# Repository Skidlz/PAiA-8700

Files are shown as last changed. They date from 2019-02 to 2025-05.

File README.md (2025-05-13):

# PAiA-8700
A redraw of the PAiA 8700 music computer in Eagle CAD</br>
Also includes:</br>
 - Python scripts for converting to and from tape dump format

 ##### TAPE PROGRAMS #####
 - [**Echo**](Tape%20Programs/Echo/) listing/binary/tape dump
 - [**Orgasmatronic Glide (O-Glide)**](Tape%20Programs/O-Glide) listing/binary/tape dump
 - [**Poly-Split**](Tape%20Programs/Poly-Split/) listing/binary/tape dump
 - [**Poly**](Tape%20Programs/Poly/) listing/source/binary/audio file
 - [**Seque**](Tape%20Programs/Seque/) listing/binary/tape dump
 - [**Pink Tunes**](Tape%20Programs/Pink%20Tunes/) listing/source/binary/tape dump
 - [**Pink Music**](Tape%20Programs/Pink%20Music/) listing/source/binary/audio file
 - [**DrumSys 0.6**](Tape%20Programs/DRUMSYS%2006/) listing/source/binary/audio file
 - [**Shazam 0.1**](Tape%20Programs/SHAZAM/) listing/source/binary/audio file
 - [**Micro-Drums 2.1**](Tape%20Programs/Micro-Drums/) listing/source/binary/audio file
 - [**Chameleon**](Tape%20Programs/Chameleon) listing/source/binary
 - Test programs source/binary/tape dump

##### EPROM PROGRAMS #####
 - [**PIEBUG**](EPROM%20Programs/PIEBUG) listing/binary/source
 - [**POT-SHOT**](EPROM%20Programs/POT-SHOT) listing/binary/source
 - [**MUS-1**](EPROM%20Programs/MUS-1) listing/source/binary
 
##### EXTRAS #####
 - memory map
 
 - 600DPI scan on the Seque overlay

##### NOTES #####
.asm files can be assembled with [Frank's Cross Assembler (AS65)](http://www.kingswood-consulting.co.uk/assemblers/).

##### BUGS #####
###### DrumSys ######
The original code listing for DrumSys contains an error in the code/data alginment. Two versions are included here, and they correct the error in opposite ways. One shifts the data, while the other shifts the code.

###### Echo ######
Echo has a relative branch that is out of range. At address $080 is "beq STAR". STAR, being at $000, is a byte too far away, and the branch instead points to $100. This has not been corrected. Adding a "jmp STAR" at address $100 is a possible fix to the issue.

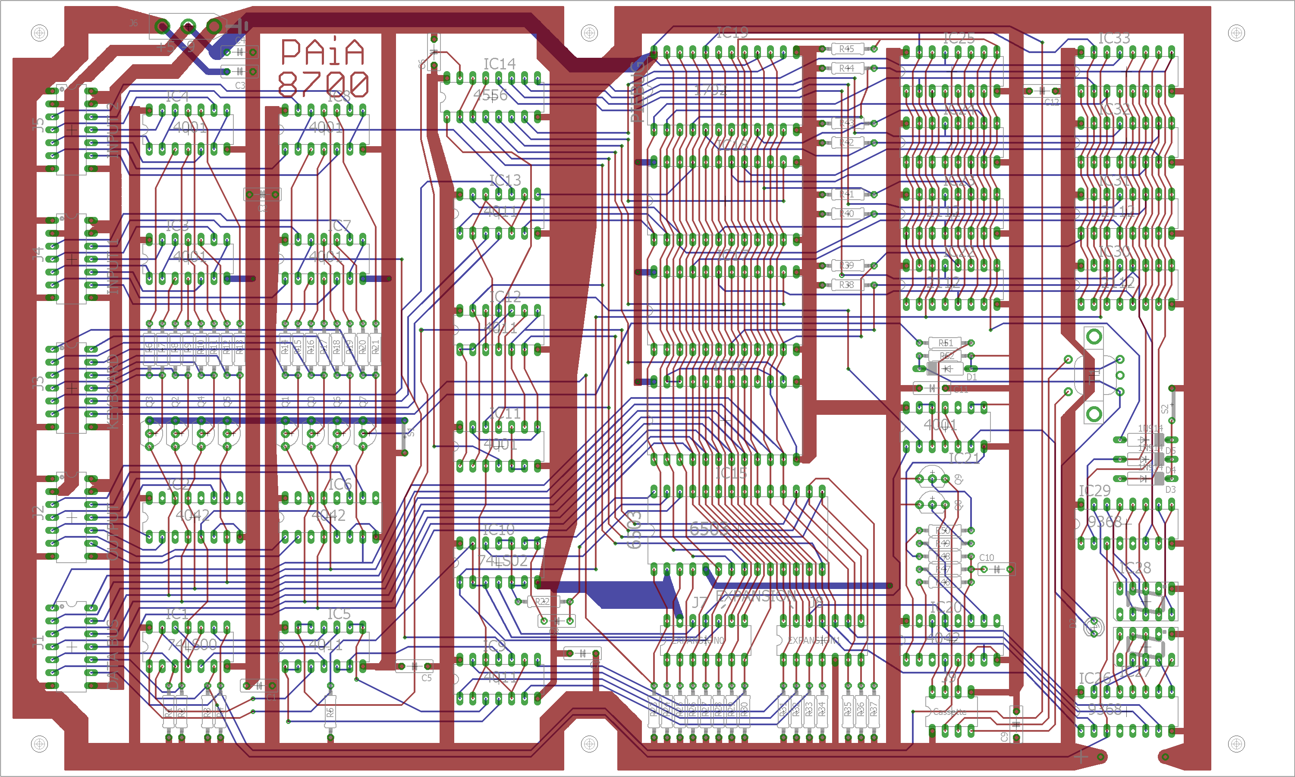
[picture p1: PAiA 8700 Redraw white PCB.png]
PCB


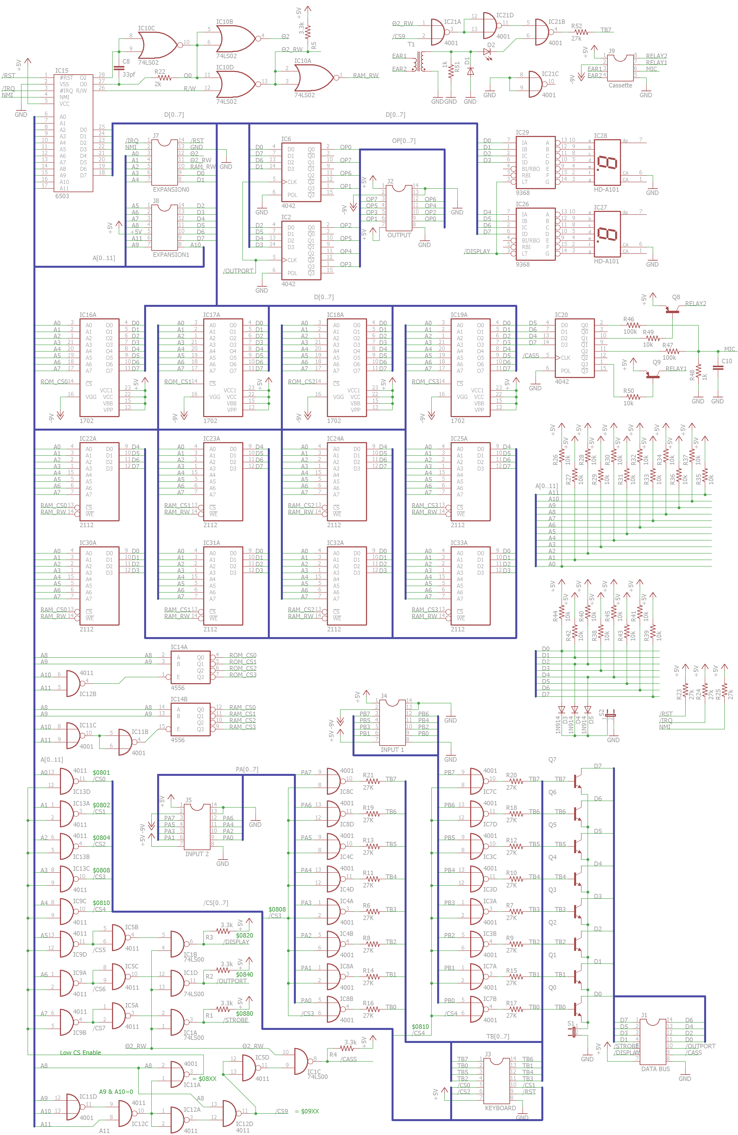
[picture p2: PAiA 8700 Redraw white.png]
Schematic


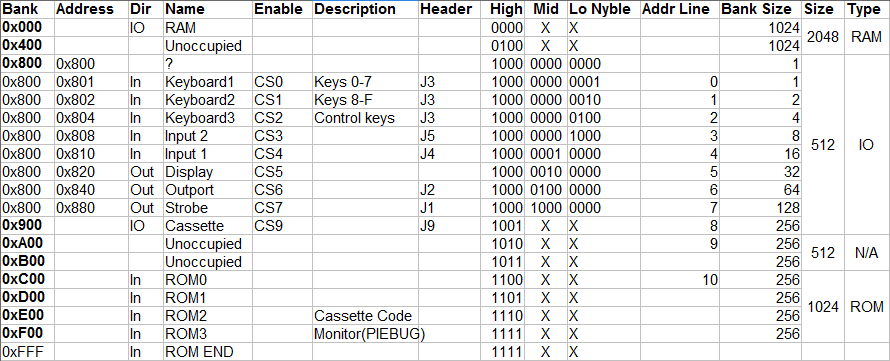
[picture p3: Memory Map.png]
Memory Map


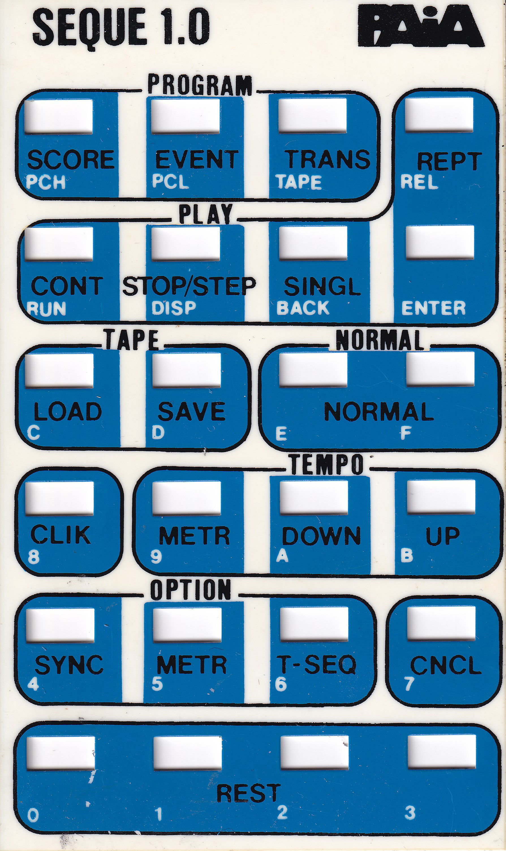
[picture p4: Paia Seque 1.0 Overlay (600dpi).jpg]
Overlay


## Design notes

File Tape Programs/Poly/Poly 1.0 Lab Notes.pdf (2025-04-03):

We've come a long way over the last year in terms of developing a series of digitally interfaced modules that will allow computer control of music synthesizers. I suppose that the time has come to look at tieing them all together, with the computer, and begin doing interesting things.
I bad wanted to start with "the ultimate sequencer programs" but am not completely happy with them yet. They still need a little polishing.
Instead, we'll start with what sbould be another popular system:

THE POLYPHONIC SYNTHESIZER Which is a much simpler job than the ultimate sequencer.
I would like to go through the system showing specific ways to do things for a variety of manufacturers equipment but that just isn 't practical. Instead, we'll look at a completely PAIA based system and assume that if you are using different equipment you are familiar enough with it to make whatever changes are necessary.
Oh, one more thing before we begin, be sure that you understand that there are a wide variety of ways to do poly-_ phonic synthesizers. This is only one of them. 1 hope that the algorhythm used here works for you. It's one of maey, some with sort of special quirks that make them useful in certain situations but difficult to work with generally - This seems to be good general purpose way. Ready? W e have lots to do and little space and time; here we go.

THE HARDWARE

Most of the hardware that we'll be using has been described here over the last year (or so). For the controller portion of this system we'll need:
1) AN ENCODED KEYBOARD
8782 or EK-3 retro-fitted
equivalent
2) A COMPUTER
An8700 in it's minimum configuration will run the programs tliat we '11 list. A cassette interface system is useful to the point of being almost mandatory. We'll show some new panels and stuff to make it all pretty.

figure 1. computer/synthesizer sub-module placement.

By
Johns. Simonton, Jr.
3) DIGITAL/ANALOG CONVERTER AND SAMPLE AND HOLDS
the 8780/8781 system.
And, of course, we'll also need
as much synthesizer as we think is necessary.
With all of the items listed, various wiring schedules have been mentioned for doing various non-computer things. W e now need to establish some standaids for this new use, a computer based polyphonic system.
If we choose wisely, we should come up with a standard that has plenty of room for future growth. Some consideration has gone into the system which follows and I believe that it will serve our needs for some time to come. Maey of you will already have much of this wiring done, as much of it is simply an extension of what we've done ~ Check carefully to be sure your wiring is to this new standard. THE KEYBOARD
Let's go ahead and configure this system from the beginning so that the computer fits in the synthesizer cases that we1ve been using. All of the parts will fit in the case like this:

PAIA 8700 COMPUTER, POWER_SUPPLY AND KEYBOARD ENCODER
RETRO-FIT TO 4700 OR 8700 SERIES KEYBOARD, | 23

24

### ENCODER BOARD ROW

0 7
00 0
~ TO | KEYBOARD BUSSES | | ~ TO FIG.2 | DIODES/ SWITCHES
KEYBOARD ENCODER 1/0 CLUSTER (WIRE OIRECT) 001 01 | | OIPHEAOER TO 8700 J4

### COLUMN

3...,..lt-"-ttf"""'"l:l:t-~it""""i:li"'"""ttt-""""1"1"""1:1:t-

4~~~-'-4i9-'~l--'-E9-"-ttlr"-tit"""-ifr"

5-'l~~~~'-"1!-L@-A..(:1~~"'49-J'

6-lliµ..-'9-"'"'9--d41li-L'9-~,__-+-+-

7_,1---t--+-_.,t---+--+--+--+-

At tbis stage you may have more dis-assembly to do than assembly. Particularly, the old control panel of the keyboard is removed to make room for the computer and any unregulated supply tha.t was powering your keyboard encoder is replaced with a PS-87 wbich supplies all digital power for the entire system. This is going to give you a few parts for your "bench stock", the old power supply components and a couple of pusb.-buttons, but some of the parts we will be re-using. Don't throw anything away.
KEYBOARD
TO ENCODER CONNECTIONS
Maximum useability of the system would seem at first to depend on where the AGO keyboard switches appear in the key ma.trix. We want them in the middle so tha.t we have as much room to transpose down In pitch as we do for up-scale transpositions. Some 8782 instructions had the keyboard placed 8 switch positions below where it should be for tbis ideal. The "column" connections are flne, but the "row" connections on these keyboards will need tobe "slid up one" so that they conform to the configuration as shown in figure 2.
This will place the keyboard more or less in the middle of the matrix as shown in figure 3. This is really a fine point, and the system will work OK in most applications almost no matter where in the matrix the keys are, but go ahead and change now so that you won't be limited In the future. ENCODER MODIFICATIONS

W e don 1t need any of the "trick" thlngs that we used when we didn1t have a computer (the orgasmatronic glide circuit, etc. ) , just the barebones encoder. You may remove all push-buttons slide switches, pots etc.; most of these will come out when you remove the old front panel. ENCODER TO COMPUTER
If your system previously bad a

02
03
04
05
START

FIG.3: 'The Keyboard as Matri xed

FIG.4

TO DATA BUS Jl

TO ABO
EXPANSION AB 1
J7 AB2 AB3

DIP HEADERS

Dl\•25
FEMALE
TO 8780/ 8781
1 1

'-1-t--t--+-~l----t--<2
~-+--+-+-+----''--< 3 .._,-+-+--+--~C4

"-'f-+-+-~< 5
'--+-+--->-< 6
""--1"--+-<7
8
~-------'--<9

'-1--------.....-<14 • ~--------+-<15

~----------''-<16
~---------....... -<17
.-----------....... -c:18 .------------''-<19

FIG.5: COMPUTER TO 8780/8781
DB-25 female connector tied to the output of the encoder, desolder it (carefully - whistllng may make the job seem easier). In place of the DB-25 connector, we now need to termlnate the output of the encoder In a DIP header that will mate with the INPUT PORT #1 (J4) connector on the rear edge of the 8700 computer board. These connections should be made as in fjgure 4.
These connections should also be made carefully and the DIP header pins weil heat-sinked to prevent melting the plastic header. NOTE that while maey of the non-computer applications used the STROBE line to trigger the D/ A, here we :lgnore tbis line and lnstead use the STROBE as the seventh data bit (D6) of the interface. Similar1y, the encoder•s START line becomes the 8th data bit (D7). Also, you will notice that power to the encoder is picked up through this connection from the 8700 itself. COMPUTER TO SYNTHESIZER HEAD So that our resulting system can
be easily broken down into two separate units (computer/keyboard and synthesizer head), this is the place to use the DB-25 connector that was salvaged from the old keyboard front panel. Connections should be made between the female DB-25 connector and a pair of DIP headers like those in figure 5.

NOTE that the first header (P2) provides data lines and the CASS select signal (our 8780/8781 shares this output structure) while the second connector (P3) provides the address lines required by the QuASH.

8780/8781 WIR.ING

The male DB-25 connector that terminates the cable to the 8781 is wired in wha.t is essentially an expanded version of our previous standard so that here you are faced more with adding wires than re-arranging them.
Connect these elements together as in figure 6.

J2 ....-
8780 | J l FRON
CO T PANEL NNECTIONS | J3

SYNTHES IZER
POWER B US

WIPER,
R34

V +5~

_l_ ..-1 t-
-=- \

ROY ~/!

07~
060-
050-

0
eo | 040 ....
CO | 03"
02 0-
01"

Oo~
1-i--,
-9v- 1 +9~ ri.

t+o>- -L>---

-9 | Cl

Tbis wiring schedule is examined
in detail in the 8781 QuASH assembly manual. An important thing to notice here is the way the grounds are handled. Note that the ? (ground) pin on
the rear of the 8780 board serves as the central ground for both analog (synthesizer) and digital power distribution. This grounding scheme is important to prevent ground loop problems and should be followed exactly. This entire 8780/8781 assembly should be mounted in the synthesizer head cabinet.
FINAL ASSEMBLY
Finally, make arrangements for physically mounting the computer in the keyboard case by first mounting the computer to a suitable front panel as shown. (See figure 7)*
And don 1t forget to provide a socket a.t the 8700's expansion connector (J7) or to mate P3 with this socket before assembling the computer/front panel. If the cassette interface is being used, terminate the input and output lines in miniature phone jacks as shown in figure 8.

Plug all the connectors together and you should be ready to load a program.

/

J9

TO TAPE
INPUT

FROM TAPE '------o--u OUTPUT

FIG.8: CASSETTE CONNECTIONS

THEPROGRAM
The polyphonic program that we'll be using is called simply:
POLY 1.0
This program supports up to 8 output channels the way that it is written and can be easily modified to provide for more.
POLY 1. O allocates synthesizer resources to keyboard requirements using this algorhthm:
1) Output all notes appearing in the output buffer area (NTABLE) after adding the corresponding transposing figure from TTABLE. Go to 2.
2) Wait for keyboard scan to start and place a list of all keys currently being held down in the input buffer area (KTABLE), When buffer full or scan complete go to 3.

MOLE X EOGE CONNECTOR

1
1
1 | o+5
1 | o-L
- l | 085

olffi" 1
1 | OF2
Ofl 1 | OA3 1
OA2 | ;; 1 | ....
eo OAl 1
1 | OAO
OM 1 | oojA
~ | 0+9
1
1 | OGNO
1 | 0-9
1
!

!'V 15 CONOUCTOR D' CABLE

r- t.- | '"".i -: : -l | :-:1 : -:
~· ⁻ r- r-, 1 | 1 1 - | "' .., ... .,, "' .... co .,. :!! :!!: !!: i!! ~ :!! 1 oe-25 co~~ACTOR
1 | 1 | (MAL~)
'1 0 | - | N | M | ... "' '° .... ,~ _jli+"' M | N | - | 0 | 1
-~~~-~~~~~~]--~~~~~

FIG.6
25

### OPTIONAL

3) Clear the trigger flags (D6) of all notes in NTABLE (the output buffer).
4) Compare each entry in the input buffer (KTABLE) to each entry in the output buffer (NTABLE). If they are the same, set the trigger bit of the NTABLE entry and eliminate (zero) the entry from KTABLE. If all available outputs are used, or if all keys down find a horne go to 1.
5) Place the rernaining input buffer entries in output buffer locations which do not currently correspond to a down key (those in which D6 is cleared). When all input data has been placed or all channels available have been used go to 1.

There are a number of subtle irnpli„ cations here and unfortunately not enough space to cover thern all.

A couple of really important ones are that if we think of "new" notes as ones corresponding to keys that were just pressed, this rnethod tries to place those new notes in output channels which at some point in the past were already producing those notes.
This prevents a string of identical
26

### HARIJNARE SEQUENCE

H----4-40X 1

(!"'!ll----4-40 NUT
~----4 F~AT WASHER

THE 8700 COMPUTER, CASSETTE RECORDER INPUT & OUTPUT JACKS AND EIA CONNECTOR TO SYNTHESIZER HEAD ALL MOUNT ON NEW FRONT PANEL,
A HARDWARE KIT 1S AVAILABLE - SEE END OF FIG. 7 ARTICLE

eighth notes (for example) frorn being assigned to different outputs each time they're used. Notes, once assigned, tend to. stay assigned regardless of other kcyboard activity - they don't move around in a totally unpredictable fashion as with some analog multi-note keyboards,
lt also means that once the number of output channels available is "used up" by down keys that need tobe placed, all other keys that are down are simply ignored (this is exactly what you want).
One important aspect of the above is that the program must "know" how many output channels are available to it, otherwise there is the possibility that notes may be assigned to nonexistant channels (ones that have no corresponding hardware, not too bad in itself) and further (the really bad part) future activations of the note will be assigned ~ to these non-existant outputs - producing "dead" synthesizer keys that seem not to be doing anything.
Memory location $OOEA contains the number of synthesizer chamiels available, more on this shortly.

THE PROGRAM

Shown on the next page is a disas sembled listing of POLY 1. o. Because, again, of space limitation we cannot re-print a fully documented version of POLY 1. o. lt is supplied with the assernbly and using manuals for the 8781 QuASH.

POLY 1. 0 is also available in 8700 compatible cassette-tape form for $4. oo.

LOADING AND INITIALIZING POLY 1. 0

If you have a cassette interface on your 8700 and the POLY 1. 0 tape, loading is simply a matter of connecting your tape recorder to the cassette input connectors on the 8700 and loading the tape using the following entry sequence:

o-o-o-o-o-o-F-F-0-0-1-1-T APE

If you don't have the CS-87 option, you must enter the code manually from the 8700 keyboard.

The cassette version of tbis program loads all of page zero of memory (its total requirement) and in the process initializes a couple of things that you will need to care for manually if the cassette is not available. When entering manually, be sure to set the number of outputs to correspond to the number you have available. For example, assuming that you have a system with a single QuASH, the number of channels available should be set to 4 using the followlng computer keyboard Requence:

RESET-0-0-E-A-DISP
0-4-ENTER

The tape version initializes the number of outputs at the most likely number of
4. Jf you want to use less channels (because of lack of modules, say) or ·have a system with more, do it as was shown above.
When entering the program manually, make sure the decimal mode flag in the status register is cleared by using this sequence:

RESET-o-o-F-F-DISP
0-0-ENTER
This is automatically taken care of when the tape version is loaded. USING POLY 1. 0
With everything connected, loaded and initialized, we're ready to begin making music. Go to the beginning of the program and begin running it.

RESET-0-0-0-6-RUN

If everything is working properly, we will see the 8700 displays counting quicldy, incrementing by one for each scan of the keyboard. All of the QuASH outputs should be at a very low output voltage (the program initializes them as zero) and the trigger flags for each channel should be cleared.
As we press synthesizer keys,
QuASH channels should "come alive"
and produce control voltages corresponding to the keys that POLY 1.0 has assigned ,to them. The trigger flags should be
set if the key corresponding to the
channel is currently down and clear
when the key is released.
TWO MORE FEATURES OF POLY 1. 0 While POLY is running, touching any of the keys from 0-3 on the 8700 keyboard (the first row of keys) causes the system to clear all QuASH channels to zero and wait for new data tobe assigned. You111 figure out what this is good for as you become familiar with the system.
Maybe more importantly, touching any of the keys 4-7 (the second row

# POLY 1.0

By John S. Simonton, Jr.
© 1978 by PAIA Electronics, Inc. All rights reserved.
06- | A9 00 | LDA #$00 | G9- | A6 E9 | LDX $E9
08- | A2 18 | LDX #$18 | 6t:l·- | B4 CF | LDV $CF,X
0A- | 95 CF | STA | $CF,X | GD- F0 1D | BEQ $088C
0C·· | CA | L)D: | GF·- | P.2 09 | LDX | #$09
01)- | D0 FB | BNE ~80A | 71- CA | DEX
0f- | A2 08 | LDX #$08 | ?2- | F0 F1 | BEQ $0865
11- | B5 D7 | LDA $D7,X | ?4- | 98 | Wf1
H- | 18 | CLC | 75- | 55 D7 | EOR | $07, X
14-· | 75 DF | ADC $Df,X | 77- | 0A | ASL
16- | 8D 00 09 | STA $0900 | 7f;·· | 0A | ASL
19- | 9D F7 09 | STA | $0::)F/, X | 79- | 00 F6 | BNE $08?1
1C- | A0 04 | Ll)'r' | #$04 | 7B·- | 98 | TVA
1E- | 88 | DE'r' | 7C- | 15 D? | ORfi | $D?.X
lF- 00 FD | BNE $081E | 7[- | 95 07 | srn $1)?,X
21·· | CA | DEX | 80- | CG EB | DEC | $EB
22·· | 00 ED | Bt~E | $0811 | 82„ | F0 31 | BEQ $0885
24- | A·; .:!. 08 | LDX #$0ü | 84- | A6 E9 | LDX $C9
26- | A9 00 | LDii #$00 | ü6·- | A9 00 | LDfl | #$0tl
2ü- | 95 CF | STA | $CF, X | Bü·- | 95 CF | srn $CF,X
2n- | CA | DEX | üA- F0 D9 | CEQ | $0865
2D- D0 F8 | 8NE | $0828 | iiC·- | fi9 01) | LDfi #$00
2D·- | A2 08 | LDX #$0ü | 8[- | A2 09 | LDX | #$09
2F- | 2C 1€1 08 | BIT | $0810 | 90·· | CA | l)D(
:32- | 30 FD | BMI | $082F | 91-- | F0 22 | BEG! | $0ü85
:54- | 2C 10 08 | BIT $0810 | 9J-~ | [:4 CF | LDV $CF„ X
J7- | 10 0F | 8MI | $0848 | 95-· | rn F9 | BEG! $0890
:,$9„ | 50 F9 | BVC $0834 | 97·- | <"•C" ;„J CF | srn $CF,X
18· | AD 10 €18 | LC•H $0810 | 99- | e··· 1.:!. 139 | LDX | #$09 .~E- | 95 CF | srn $CF .. i·( | 98- | CA | DEX
4()- | CD lÜ 08 | CMP $081~) | ~1C- | rn 1? | BEQ | $0885
41- Hi FC | DEG! | $0840 | 9(- | fl9 4iJ | LDf1 | #$40
45- | Cli | [)[:~ | 110- | 35 D? | titiD | $1)?, ~-(
4f.i·- | D0 t::C | BNE | $0834 | n2-~ | [)0 F? | 8Nt $(1ü98
4:?,·- | E6 E:J | INC | $E:C: | fl'I·· | A9 :30 | LDf: | #$t:ü
41'1- | 115 E:J | LDil | $Eü | 116· | ·:;;:- ,,;.J D? | AN!) | ~w?„ ;:.;
4C- | 8{) 20 08 | STA | $0820 | fl8··· | 95 D? | STH | $[:i~-;.J >~
41- | [ff | NOP | lifi- | 98 | TWI
50-- | Eli | NOF' | nB-- | 15 D7 | ORfl | $[)? .. >~
·51- | Efl | NOP | IW-- | 95 D? | STfi | $L)7, ::<
5:e:· | f:5 CA | LC<li | $EA | tiF·· | C6 t:B | [JEC | $[(:
54·· | 85 [!3 | srn $[8 | 81„ | F0 02 | BW | $0::385
56-- | A2 08 | LDX #$0::3 | 8}·· | 1)0 !)? | BNE | $0ü8C
5ü- | A9 BF | Ll)fi #$8F | B5·- | 2i3 00 ff | JSI<: | $ff00
5ti- | 15 D? | fl~j[< | $1)?, :..; | Dü-- | C9 04 | CMP | #$04
'5C· | 9'5 D? | srn $Ci·?_.>{ | Dfi- | 80 03 | DCS | $0:38F
5E·- | cn | DE~( | 8C-· | 4C 06 fl:J | .JMP | :$\X106
5F·- 1)0 17 | BNE $0858 | or·- C9 0ü | CMP | #$08
61·· | A9 09 | Ll)fl | #$0::) | Ci·- | 80 0"' ·.J | BGS | $0:::c8
G3-- | 85 Eo _„ | STfl | $E9 | r···'·· ~,,; | 119 2E | LOn | #$2E
G5- | C6 (9 | DEC $ES: | CS· | 4C 0:0 0(1 | JMP | :$01'J~38
Gr· | F0 ;;:.;; | BEG! | $088C | C8„ | 4C üF 00 | JMP | $0ttüf
on the 8700) provides a tuning function | You may want to use multiple VCO's
and causes all QuASH channels to pro- | mixed into a single voicing circuit,
duce the same note with the trigger | (See figure 9), or what amounts to a
flags set, allowing all oscillators to be | complete synthesizer for each con-
set to the same pitch. The note pro- | trol channel or anything in between,
duced corresponds to the 2nd C on a | (See figure 10).
standard configuration 3 octave key- | A word of ad.vice: in your beginning
board. THE CHANNELS MUST BE | stages of learning to use this system,
C LEARED AFTER TUNlNG by touching | you should try to stick to configuration
the first row of 8700 keys. | in which all of the channels are produc-
ing the same "type" of sound - as close
THE SYNTHESIZER | to identical as possible. As your skills
progress and you develope a feel for There are an almost unlimited number how POLY 1. O is going to massage data
of ways to use the multiple control | you can work up to using some output
voltage produced by the QuASH and | channels to set VCO pitches while
POLY 1.0. | 27

c

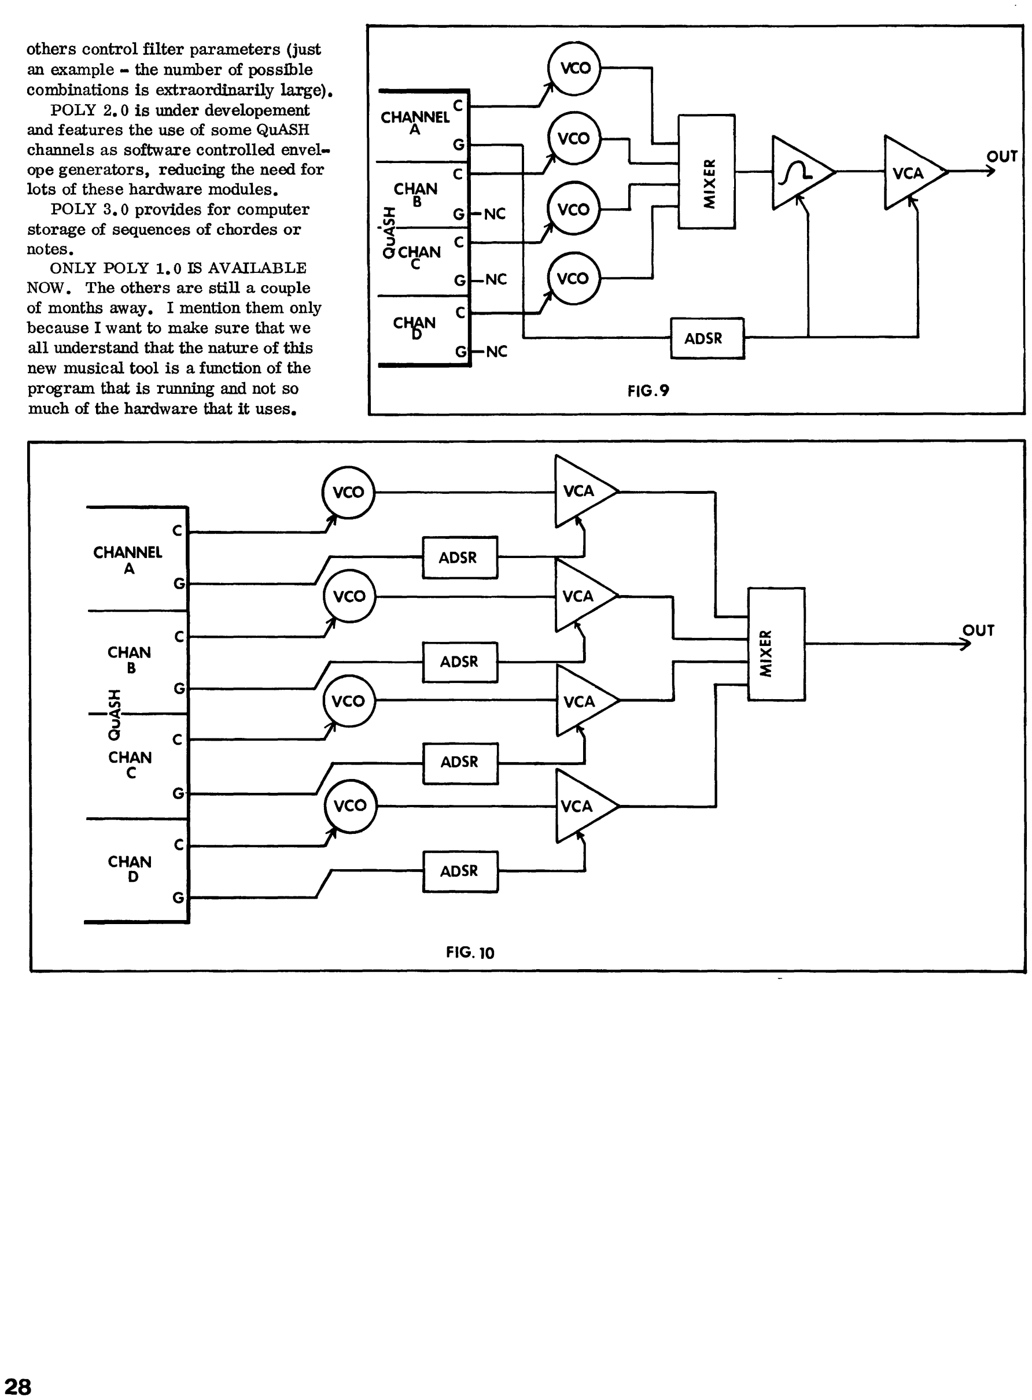
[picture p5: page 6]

others control filter parameters (just an example - the number of posslble combinations is extraordinarily large), POLY 2. 0 is under developement and features the use of some QuASH channels as software controlled envelope generators, reducing the need for lots of these hardware modules.
POLY 3, O provides for computer storage of sequences of chordes or notes.
ONLY POLY 1.0 IS AVAILABLE NOW. The others are still a couple of months away, 1 mention them only because 1 want to make sure that we all understand that the nature of this new musical tool is a function of the program that is running and not so much of the hardware that it uses,

c
CHANNEL
A
G

c
CHAN
B
:r G
-<t' "'
::>

### 0 c

CHAN
c
| G

c
CHAN
D
| G

28

CHANNEL C
A

CHAN
B
:r | G | NC
"<t' "'
::> | c
OC'rN
G NC
C~N c
ADSR
G NC

FIG.9

ADSR

"' | OUT w
ADSR | X
~

ADSR

ADSR

FIG.10

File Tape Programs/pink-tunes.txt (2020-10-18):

;
;   PINK TUNES
;
;   A COMPOSING PROGRAM
;   FOR FOUR PART HARMONIES
;
;   BY JOHN S SIMONTON, JR
;   (C) 1978 PAIA ELECTRONICS, INC
;
        ORG     0000
BEG     JMP     BRAK    ; BREAK VECTOR
STAR    JSR     INIT    ; SETUP SYNTH - MUS1
        LDA     KBD     ; INITIALIZE RANDOM
        STA     *NTMP+01 ; NUMBER GENERATOR
LOOP    JSR     SET     ; INIT PINK TUNES
LP0     JSR     NOTE    ; PLAY NOTE, READ AGO
;
; CHECK FOR ADDITION TO CANDIDATE
; NOTE TABLE
;
MAIN    LDA     *KTBL+08 ; ANY KEYS DOWN
        BEQ     OUT1    ; NO-CHECK FOR TIME OUT
        CMP     *TEMP   ; YES-A NEW KEY?
OUT1    STA     *TEMP   ; SAVE FOR NEXT TIME
        BEQ     OUT     ; BRANCH IS SAME KEY
;
        LDX     10      ; IF NEW KEY SHIFT
LP3     LDY     *NBUF,X ; ALL 16 CANDIDATES
        STA     *NBUF,X ; DOWN BY ONE
        TYA
        DEX
        BNE     LP3     ; NOT DONE-LOOP
;
; NOW CHECK FOR CLOCK TIME OUT
;
OUT     LDA     *CLCK   ; GET MASTER CLOCK
        BNE     TEST    ; AND IF TIMES OUT
        LDA     *TMPO   ; SET TO TEMPO VALUE
        STA     *CLCK   ; CALL SUB FOR NEW
        JSR     ALOC    ; NOTES (IF NEEDED)
        LDA     *LNTH   ; GET CYCLE STATUS
        STA     DISP    ; SHOW IT AND IF ZERO
        BEQ     TEST    ; CYCLE IS COMPLETE
        DEC     *LNTH   ; IF NOTE DONE, DECREMENT
        BNE     TEST    ; IF NOTE ZERO NOW LEAVE
        JSR     SET     ; IF ZERO, RE-INIT
        JSR     ALOC    ; GET FIRST NOTES AND
        BEQ     LP0     ; BRANCH ALWAYS TO PLAY
TEST    JSR     DECD    ; GET A COMMAND - MUS-1
        BNE     TST2    ; NOT ZERO, NEXT TEST
        LDX     03      ; COMMAND0, NEW TUNE
                        ; SET POINTER/COUNTER
TST1    JSR     RNDM    ; GET RANDOM NUMBER
        STA     *NTMP,X ; NEW INITIAL RANDOM
        DEX             ; POINT TO NEXT
        BNE     TST1    ; NOT DONE - LOOP
        BEQ     LOOP    ; BRANCH ALWAYS
TST2    CMP     01      ; COMMAND 1, TUNNING
        BNE     TST4    ; NOT 1, TEST NEXT
        LDX     04      ; 4 OUTPUT BUFFERS
        LDA     5C      ; PUT MIDDLE C IN ALL
TST3    STA     NT0B,X  ; OUTPUT BUFFERS
        DEX
        BNE     TST3    ; NOT DONE-LOOP
        BEQ     LP0     ; BRANCH ALWAYS
TST4    CMP     02      ; COMMAND 2 STOP
        BNE     LP0     ; NO COMMAND - LOOP
        JSR     SET     ; CALL TO ZERO OUT-BUFFS
        JSR     NOTE    ; THEN MUTE SYNTHESIZER
        BRK

        ORG     0088
TIMED   DB      02      ; 0x0088
TIMEC   DB      04
TIMEB   DB      01
TIMEA   DB      01

MASKD   DB      F2      ; 0x008C
MASKC   DB      F0
MASKB   DB      F3
MASKA   DB      F3

NBUF    DB      5A      ; 0x0090 - CANDIDATE ARRAY
        DB      5D
        DB      5F
        DB      62
        DB      64
        DB      62
        DB      5F
        DB      5D
        DB      5A
        DB      58
        DB      56
        DB      53
        DB      56
        DB      58

RND0    DB      00      ; 0x00A0 - 5 DICE/RANDOM NUMBERS
        DB      00
        DB      00
        DB      00
        DB      00

NOIS    DB      00      ; 0x00A5
        DB      00
        DB      00

LNTH    DB      00      ; 0x00A8 - Cycle length

TMPO    DB      FA

        ORG     0100
;
;       RANDOM NUMBER GENERATOR
;
; ESSENTIALLY A 22 BIT LONG SHIFT
; REGISTER WITH EX-0R TAPS AT
; STAGES 22 AND 21 FED BACK TO
; INPUT.
;
RNDM    TXA             ; SAVE X
        PHA
        LDA     *NOIS+01 ; LAST BYTE S/R
        ASL             ; ALIGN BITS 22 &
        EOR     *NOIS+01 ; 21 AND DO EX-OR
        ASL
        ASL
        ASL
        LDX     03      ; SET UP PNT/CNT
LP1     ROL     *NOIS,X ; AND SHIFT 3 BYTE
        DEX             ; SHIFT REGISTER
        BNE     LP1     ; BY ONE BIT LEFT
        PLA             ; WHEN DONE RE-
        TAX             ; X REG
        LDA     *NOIS+03 ; AND LEAVE WITH
        RTS             ; WITH NO. IN ACC
;
;       NEW NOTE
;
; TAKES CARE OF PICKING PINK NOTE
; FROM CANDIDATE NOTE TABLE AND
; CALCULATES AND UPDATES NOTE TIMERS
; NOTE THAT Y POINTS TO CHANNEL FOR
; UPDATE
;
NWNT    LDX     05      ; SET UP PNT/CNT
        LDA     *OUTS   ; GET COPY OF PINKING
        DEC     *OUTS   ; COUNTER, DEC ORIGINAL
        EOR     *OUTS   ; PATTERN OF CHANGED
        STA     *OUTT   ; BITS - SAVE CHANGES
        LDA     00      ; PREPARE TO SUM DICE
NW1     LSR     *OUTT   ; CHECK FOR CHANGED
        BCC     NW2     ; BIT - IF CHANGED
        PHA             ; SAVE CURRENT TOTAL
        JSR     RND     ; GET RANDOM NUBMER
        AND     03      ; MAKE RANGE FROM 0 T0 3
        STA     *RAND,X ; SAVE VALUE FOR NEXT
        PLA             ; RECOVER TOTAL
        CLC             ; PREPARE ADDITION
NW2     ADC     *RAND,X ; ADD VALUE OF DIE
        DEX             ; POINT TO NEXT
        BNE     NW1     ; LOOP IF NOT DONE
        TAX             ; USE TOTAL AS POINTER
        LDA     *NBUF,X ; GET CANDIDATE
        BEQ     DURA    ; ZERO, DO NOTE CHANGE
        STA     NTB7,Y  ; PLACE IN TEMP BUFFER
DURA    LDA     *NOIS+01 ; A CHEAP RANDOM NUMBER
        CLC             ; PREPARE
        AND     MASK,Y  ; MASK DURATION VALUE
        ADC     TIME,Y  ; ADD MINIMUM VALUE
        AND     0F      ; AND MASK RESULT
        TAX             ; USE AS COUNTER AND
        LDA     01      ; DO DURATIONS AS
NT2     ROL             ; POWERS OF 2. CARRY
        DEX             ; SET DOTS NOTE
        BNE     NT2     ; NOT DONE - LOOP
        STA     NTBB,Y  ; TIMER AND RETURN
        RET
;
;       ALLOCATION 0151
; SEES IF NEW NOTES ARE NEEDED AND IF
; SO GETS THEM. ALSO CLEARS TRIGGER
; OF NOTE OUTPUT ONCE IT HAS PLAYED
;
ALOC    LDX     04      ; DO 4 NOTE CHANNELS
LP6     DEC     *NTBB,X ; DECREMENT NOTE TIMER
        BNE     LP5     ; AND IF TIME OUT
        TXA             ; TRANSFER X REG. TO
        TAY             ; Y REG.
        JSR     NEW     ; AND GET NEW NOTE
        TYA             ; AND DURATION AND
        TAX             ; RESTORE X
LP5     DEX             ; DECRIMENT COUNTER
        BNE     LP6     ; IF NOTE DONE - LOOP
        LDX     04      ; AGAIN, FOUR CHANNELS
AL1     LDA     *NTB7,X ; GET NOTE FROM TEMP
        STA     *NT0B,x ; BUFFER, SAVE IN OUT
        AND     3F      ; BUFFER, CLEAR FLAG
        STA     *NTB7,X ; PUT BACK IN TEMP.
        DEX             ; POINT TO NEXT
        BNE     AL1     ; NOT DONE - LOOP
        RTS
;
;       SET
; PREPARES KNOWN START POINT FOR
; CYCLIC TUNES
;
SET     LDA     00      ; TO ZERO THINGS WITH
        LDY     01      ; PRESET FOR NOTE CNTRS
        LDX     04      ; DO 4 CHANNLES
LP10    STA     *NT0B,X ; ZERO OUT BUFFERS
        STA     *RND0,X ; ZERO 4 DICE
        STY     *NTBB,X ; PRESET NOTE TIMERS
        PHA             ; SAVE THE ZERO
        LDA     *NTMP,X ; SET UP RNDM'S S/R
        STA     *NOIS,X ; AND CYCLE COUNTER
        PLA             ; RECOVER ZERO
        DEX             ; POINT TO NEXT
        BNE     LP10    ; NOT DONE - LOOP
        STA     *RND0   ; ZERO 5TH DIE
        STA     *OUTS   ; ZERO PINKING COUNTER
        RTS             ; AND RETURN

        END

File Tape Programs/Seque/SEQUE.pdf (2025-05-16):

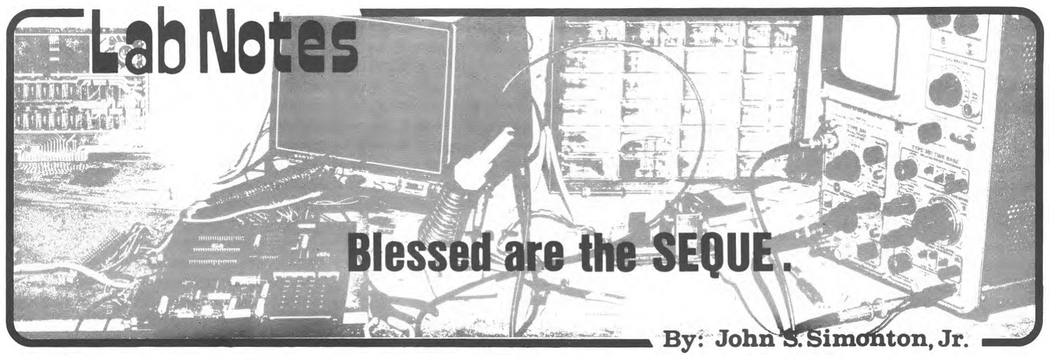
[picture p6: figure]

Last | time, we looked at the
live performance | features | of
SEQUE | 1.0. | Now we | turn our

# attention to the studio-oriented

options | | offered | by | this

# "universal" monotonic sequencer

program.

# Some of the distinctions between stage and sttidio use are

somewhat arbitrary.

# For example:

# EVENT PROGRAM

# The real-time SCORE melody programming mode that we examined

in this | first | section of this

# piece can obviously be used in a recording studio as well as it

can | on stage, | providing that

# you’re interested in recording only those things that are within

the | limits | of your physical

# abilities. But the real promise

of* a small studio (or a big one,
for that matter) | is that | it
allows us | to produce music that

# we don’t have the chops to do in

real | time. | After | all, | not

# everyone has the hours per day

that | it | takes to gain physical

# mastery of a keyboard - but that doesn’t mean that we don’t have valid musical ideas, only that we need a little help in expressing

# If a recording studio is a single thing, it’s a time machine that allows days or weeks of work

to be compressed into a | few
minutes of music. | One of the

# programming modes that we have available (EVENT) is specifically designed to operate in this type

of time-compression environment.

# In this mode we enter the music not so much as a melody, but as a

series of notes and rests. | A
series | of events which, | when
reproduced by the computer, | turn
out to be a melody (maybe).

# There is of course nothing

## 30 poiypHONa—

new about this mode of operation,

# this is the way sequencers have always worked. About the only new part is that instead of entering the events as positions of a knob

or a series of numbers, | we have
an | AGO keyboard on which to
program.
Touching | the | command

# keyboard’s PROGRAM EVENT pad puts us in this programming mode. (See

Figure | 1.) | Melody | lines | are

# entered much as they were with

the SCORE mode, except | that | the
computer is no | longer watching

# for how long we hold a key down or how rapidly the notes are played. It is now only interested

in whether a key is up or down.

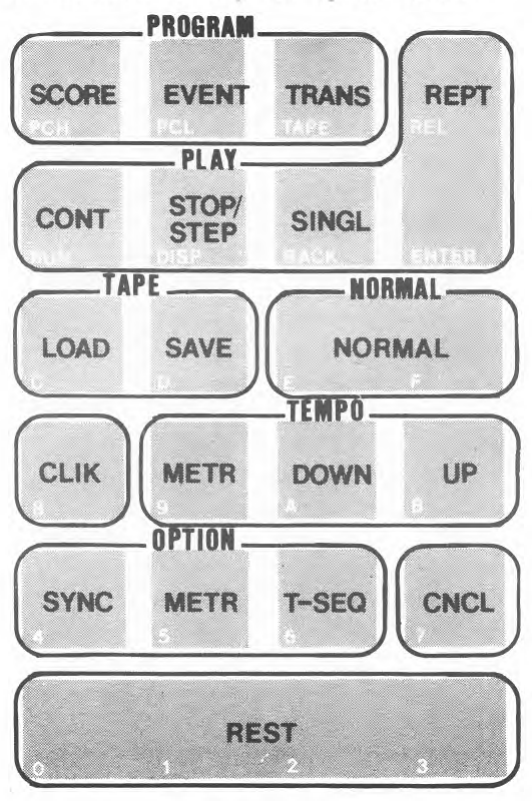
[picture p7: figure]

# Figure 1

One | of | the | major
implications | of this is that
notes in the melody are | "jammed"

# together in time, and on playback will come out exactly equally

# spaced, one note per beat. While this is OK in some cases, as a

general rule it is unacceptable;

# because it is unacceptable, we have a REST pad on the command keyboard. The REST pad provides for syncopation. It is a means of "extending" an event so that it

takes more than a single beat.

# If you’re familiar with the operation of the rest key on

something | like | PAIA’s
Programmable | Drum | Set, | you

# already have a good idea what's going on, but there still are

some surprises here.

# Your first thought may be that when you press and release a key on the AGO keyboard, that

constitutes an event. Actually,

# it’s two events as far as SEQUE 1.0 is concerned - the first when the key was pressed and the next

when it | was | released. | It's

# important to keep in mind that the REST pad can extend either of

these events.

# For example, this simple phrase:

# Figure 2

would | be | entered | from | the
keyboard by | pressing | F | and
releasing, | press A and release,
press C, | release, | press | D,
release, | press | F | and while
holding the F key down, | hit the

# REST block on the keypad, release

the F key, | tap the REST block,
play A, | touch the rest block
before letting up the A key,

# release the key, and hit the rest block once more. The measure is now completely entered, and may be played by using the REPEAT or SINGLE keys as described last time. Note particularly that on the fifth note (the second F)

## November/December 1978

where we wanted | to extend | tne

# note to a full beat, the REST pad had to be touched twice; once to extend the ’’key down” event and again to extend the "key up"

event.

# At first, having to enter two RESTs when we actually want to extend a note for a single beat may seem a pain in the neck

(undeniably, | it is) | but | the

# slight inconvenience buys us a

number of things. For example, the ability to slur notes.

# In the above example, the D could have been slurred into the F by first touching the REST pad

before releasing the D key. | This
will | lengthen the note to occupy

# the time normally used when the key is released. Then press the F key before releasing the D. This will cause the D to be entered in the next time slot without any

articulation | (triggering). | Now,
while holding the F key, | touch

# the REST pad to lengthen it to a

quarter note as covered earlier.

# After releasing the key, enter the additional REST required and

proceed as usual.
Having | each | REST | pad

# activation correspond to a "half" event (kind of) also allows us to

produce | dotted | notes as the

# exceptions that they are rather than having to make specific tempo provisions for them which must be carried over to all notes

in the sequence.
It | is | also possible to
generate | articulation | changes
whenever | a | note is extended
beyond a basic "dual" event. | If,

# for example, you are generating a series of notes where each note uses a key depression plus a REST and a key release plus a REST (four events), these notes can be performed in three different

manners. | If entered as listed
above, the note has equal | time

# allotted for note performance and

release. For a staccato style,

# the note could be entered with a key depression, release, and then two RESTs. For legato styles, the two RESTs could be entered while the key is held down, yielding three "on" events and one "off" event. Each of the above would occupy the same execution time

during | playback, | but | would
reflect | the | different
articulation styles.
Once the melody | is in the
computer’s memory, | it makes no

# difference whether it got there with SCORE or EVENT programming modes as far as the playback and options are concerned. All of

## POWPHONU

these features | (real | time | or

# programmed transpositions, single or repeat play, tempo up and

down, and tape saves or loads, etc.) work the same.

# CLICK TRACK SYNCH

# Even more powerful in the studio than the EVENT programming mode are the features added by two other command pads; CLIK and

(in the option box) | SYNC. | These

# provide a means of synchronizing

multiple tracks | of | sequencer
operation.
Once | you | start using a
sequencer for | recording, | you
begin | to find more and more

# places where it can be used to relieve a lot of tedium. The problem in the past has been that

it | is, | for | all | practical
purposes, | impossible to manually
synchronize a sequencer to | a
track that’s already on tape.

# Even slight differences in tempo soon build up to an intolerable variation in when a note is supposed to happen and when it actually does happen. Maybe there are people who could manually twiddle a tempo knob and keep

things | locked | together, | but
that's a hassle.

# Most of us are familiar with

the | classical | "click | track"
approach | in | which | a

# metronome-like "tick" is recorded on one track of a tape so live musicians can easily maintain the tempo of the original work in over-dubs. Our CLIK and SYNC command pads are simply this old concept extended into the realm

of automation.

# Touching the CLIK pad causes SEQUE 1.0 to begin producing a very rapid series of "clicks" that are machine readable and represent a standard clock rate which the SYNC option can read

and synchronize to. | The click
appears at the normal | cassette
output | jack | (where programs,

# etc., that are to be saved to

tape come from) | and when using
this option, this output is | tied

# to one of the channels of the tape recorder on which you’re

recording your audio tracks.
To | use | the click track

# option, the tape that you will be recording and mixing your audio onto must always be prepared first; you can’t record a lead part and then come back and lay down the click, it won't work like that. Before doing anything else, connect the 8700's cassette output to the input of one track

# of your recorder, start tne tape rolling in record mode, and after

allowing a | comfortable | quiet

# leader, punch the CLIK pad. Allow the tape to run much longer than you think you’ll ever need for

what | you're | going | to | be

# recording, one thing you don't want to do is run out of click in

the middle of things.

Synchronizing to the click track is simply a matter of connecting the output of the tape channel that contains the click to the normal cassette input jack of the computer, but note that some juggling of the record and playback levels of this channel may be necessary for the computer to properly write and read the

channel. In many cases, | unless
your | recorder | is capable of
providing | very | high | outputs

(similar to the earphone levels from the cassette recorders which the computer was designed to work with), you may need to use a small external amp to provide the extra gain and current drive required. If your SYNC fails to respond, try using the earphone jack signal usually provided on multi-track recorders. If this doesn’t provide enough power, try using a small portable practice
amp | (such as a Pygmy or Pignose)
whose earphone | output | should
adequately | drive the cassette
input jack of the computer.

# Assuming that you have some rhythm sequence (ordinarily the first laid down) in the computer memory and that you're getting

ready to record it as audio,

# proceed by first punching into the T-SEQ option (if you plan to

use | it) | then touch the SYNC

# control pad. Roll the tape with the click track channel set to playback and the audio going to one of the other tracks which is naturally in record mode. Before the quiet leader ends, touch the REPT/PLAY command pad and hold

it. When the click track starts,

# so will the sequence. When enough

of the track is | laid | down,
terminate | the | play | mode by
touching the NORMAL pad.

# It is necessary to select the SYNC OPTION last in the above sequence of events because once this option is asserted, a click track must be coming in on the cassette port for the computer to

recognize any further commands.

# If you find yourself with a "dead" computer caused by CLIK being selected with no click track present, you can either run a tape which has a click track or

November/December 1978 | 31

# reset the computer and run the

program again.
In | situations | where the

# sequence is not to be played from the first down-beat, the SYNC OPTION should be enabled before rolling the tape and REPT/PLAY punched in when the time comes

for the sequence to start.
A little | constructive play
will | go | a | long way toward
familiarizing | you | with | the
capabilities | of this powerful

# option. Here are some we haven’t mentioned yet: You have probably already noticed the somewhat cryptic METR designations that appear in both

the | OPTION and TEMPO control
boxes. | And | probably | you’ve
figured | out | that | it | means

# metronome (a handy thing in any studio). But this is kind of a super metronome because not only

does | it have a ’’pendulum” (which
shows | in the computer’s | twin
displays) | and an audible click

# (which you hear from 'the beeper)

but | it | also | provides | an

# electrical output in the form of a short positive going pulse that appears as D7 of the D/A output channel (which in turn shows up on the Flag 2 pin jack of the D/A’s front panel). This pulse is

enormously | useful | in

# synchronizing external devices (a

Programmable | Drum | Set, | for
example).

# Since both the SYNC and METR options may be asserted at the same time, the external device can be synched to a pre-recorded

audio track.

# The METR pad in the TEMPO control box is obviously the

tempo control for the metronome.

# Like the other tempo controls that we looked at last time, this one works in octaves. Each time the pad is touched the metronome tempo doubles until the maximum

rate is reached, | then the next
touch causes | the tempo to "fold
back" to the minimum rate.

# It may be somewhat out of sequence (?) to mention here that the tempo of the metronome is the tempo at which sequences stored

in EVENT mode will play back,

# though of course, the TEMPO UP and DOWN command pads will also alter the tempo of the sequence

once saved, | as outlined | last
Another | point | - | When

# electrically synchronizing things to the click track, the METR TEMPO can still be varied to accomodate different timings, and

## 32 POiyPHONU—

# integrity of the timing will be

preserved.

# And a hint - the metronome "beep" can also be recorded on

tape | to | provide | a | "human

# readable" click track (though it must be saved on a different

track than the CLIK).

# The only other command pads that we’ve added are STOP/STEP (a means of stopping the sequence without "forgetting" where we were as well as single stepping through the sequence) and CONT (continue) which allows us to pick up from the point where we STOPped. This feature can provide

easy introductions | to | songs.

# STOP/STEP through the piece until you reach the REST just prior to the point where the introduction should start. When the CONTINUE pad is touched, the introduction

will | play, | leading into the

# 1 *ish 1 nad rhe space and

time | (and | for | that matter,
knowledge) | to | go | into | some

# expository statements on the art

of small studio multi-tracking,

# but I leave that to an old friend

and | new-comer | to Polyphony’s
pages, | Craig Anderton. | I hope

# that Craig's and my work will complement one another in this

area - I think it will.

# I also wish I had the space to go into a detailed analysis of

how SEQUE 1.0 works. I don't. | If
you’re | really interested, | the
documented | assembler | listing
which | follows is tremendously
meaty (though sketchy in parts). Careful study of the code used,

# in conjunction with the comments

given, | should be valuable in
learning more | about | software
generation and execution.

# SEQU COMMAND

# PROGRAM

SCORE | - Saves melody sequence in real time.
EVENT | Saves melody sequence as regularly spaced events.

# TRANSPOSE- Saves transpose

| sequence as events.

# PLAY

REPEAT | - Plays sequence from be- ginning, cycles until stopped.
SINGLE | - Waits for key on AGO then plays sequence from the beginning. Stops at end of melody.

# STOP STEP - Allows stops or pauses

| during playback.

# CONTINUE - Starts melody playback

| from where you are in memory.

# TAPE

SAVE | - Dumps current Melody and Transpose sequences to mag. tape.
LOAD | - Loads M & T sequences from tape.

E 1.0

# SUMMARY

# OPTIONS

TABLE - Selects transpose sequence table as source of trans- positions (otherwise AGO is source).

# METRONOME-Initiates visual metro-

| nome display and a "beep".
SYNC. | — Shuts down internal timing and accepts pre- recorded click-track for timing information.
CANCEL | - Turns all selected options off.

# TEMPO

UP | - Doubles tempo of melody sequence.
DOWN | - Halves tempo of melody sequence.

# METRONOME-Doubles speed of metro-

| nome display and "beep".

# MISO

NORMAL - The "normal synthesizer" mode. Does not alter stored sequences.

## November/December 1978

■0010 | ;********************************
0020 | :* | *
0030 | :* | SEQUEL 0 | *
0040 | :* | *
0050 | :* MONOTONIC SEQUENCER PROGRAMS *
0060 | :* | *
0070 | * | BV | -
0080 | * | J0W4 S | SIMONTON, JR. | *
0090 | :* | *
0100 | :*<C) 1978 PAIA ELECTRONICS, | INC*
0110 | :* | ALL RIGHTS RESERVED | *
0120 | :* | *
0130 | :********************************
0140 | .
0150 | DEFINE ADDRESSES OF LABELS
0160 | :
0170 | BEEP | DL 1F22
0180 | DECD . DL 1F00
0190 | CASS . DL 1EAA
0200 | DBIT . DL 1E49
0210 | SBIT | DL 1E25
0220 | OUTP . DL 0840
0230 | DSP | . DL 0820
0240 | KBD | . DL 0810
0250
0260 | MTB3 | DL 0303
0270 | MTB2 . DL 0302
0280 | MTB1 . DL 0301
0290 | MTBL | DL 0300
0300 | TTBL | DL 02C0
0310 | :
0320 | BUFF . DL 00F0
0330 | KBUF . DL 00EC
0340 | PBUF . DL 00EB
0350 | MPNT . DL 00EA
0360 | TPNT . DL 00E9
0370 | MEND . DL 00E8
0380 | TEND . DL 00E7
0390 | TRNS . DL 00E6
0400 | CNTR . DL 00E5
0410 | TTRN . DL 00E4
0420 | LSTL . DL 08E3
0430 | STUS | DL 00E2
0440 | TPO | . DL 00E1
0450 | METF . DL 00E0
0460 | MTRC | DL 00DF
0470 | DUMV . DL 0003
0480 | :
0490 | :
0500 | :
0510 | . OR 1008
0520 | :
1000- | A9 00 | 0530 | STAR LDA 00 | START / RESTART
1002- | 85 E2 | 0540 | STA *STUS | CANCEL OPTIONS
1004- | A9 0C | 0550 | LDA 0C | NRML COMMAND LINK
1006- | 8D 7B 11 | 0560 | StA ACTN+01 | PLACE COMMAND LINK
1009- | 4C 18 11 | 0570 | JMP COM | JUMP TO COMMON

0580
0590 | NORMAL OPERATING MODE - DOES NOT ALTER
0600 | :T-SEQUENCE OR M-SEQUENCE
0610
100C- | B0 05 | 0620 | NRML BCS NRM1 | FIRST PASS THROUGH
100E- | 85 E6 | 0630 | STA *TRNS | ZERO TRANSPOSE
1010— | 8D 20 08 | 0640 | STA DSP | AND DISPLAVS
1013- | A5 EC | 0650 | NRM1 LDA *KBUF | CHECK FOR NOTES
1015- | D0 04 | 0660 | NRM2 BNE STOR | ZERO- NO NEW KEV
1017- | A5 EB | 0670 | LDA *PBUF | SO GET OLD KEV
1019- | 29 3F | 0680 | AND 3F | CLEAR BOTH FLAGS
101B- | 85 EB | 0690 | STOR STA *PBUF | SAVE AGAIN
101D- | 60 | 0700 | RTS | AND RETURN
0710
0720 | :PROGRAM TRANSPOSE MODE - NOTE PLAVED
0730 | :IS "KILLED" WHEN KEV IS RELEASED
0740
101E- | 80 0A | 0750 | TLOD BCS TL1 | :FIRST PASS, | INITIALIZE
1020- | 85 E6 | 0760 | STA -TRNS | ZERO TRANSPOSE FIGURE
1022- | 85 EB | 0770 | STA -PBUF | ZERO OUTPUT NOTE
1024- | 85 E7 | 0780 | STA -TEND | ZERO TABLE END POINTER
1026- | A9 80 | 0790 | LDA 80 | :TURN T-SEQUE OPTION
1028- | 85 E2 | 0800 | STA -STUS | 0
102A- | A6 E7 | 0810 | TL1 | LDX -TEND | :GET TRANSPOSE POINTER
102C- | 8E 20 08 | 0820 | STX DSP | : SHOW IT
1020 | :
1030 | REPEAT PLAV MODE - WHEN FIRST ENTERED
1040 | M-SEQ AND T-SEQ POINTERS ARE SET TO ZERO
102F- | A5 EC | 0830 | | LDA -KBUF | GET THE NOTE '
1031- | F0 06 | 0840 | | BEQ TL2 | ZERO- NO KEV, SAVE
1033- | C5 EB | 0850 | | CMP -PBUF | KEV SAME AS LAST?
1035- | F0 05 | 0860 | | BEQ TRTN | VES - LEAVE
1037- | E6 E7 | 0870 | | INC -TEND | POINT TO NEXT LOCATION
1039- | 9D C0 02 | 0880 | L2 | STA TTBL, X | SAVE TRANSPOSE
103C- | 85 EB | 0890 | RTN STA -PBUF | AND OUTPUT AS NOTE
103E- | 60 | 0900 | | RTS | THEN RETURN
| | 0910
0920 | PROGRAM SCORE MODE - USES REAL-TIME CLOCK
| | 0930
103F- | 20 84 11 | 0940 | MSAV JSR MSV1 | CALL SAVE MODULE
1042- | E6 E5 | 0950 | | INC -CNTR | INCREMENT THE TEMPO
1044- | 60 | 0960 | | RTS | COUNTER AND RETURN
| | 0970
0980 | CONTINUE PLAV MODE - DOES NOT RESET
0990 | M-SEQUENCE OR T-SEQUENCE POINTERS
| | 1000
1045- | 38 | 1010 | CNTU SEC | SKIP INITIALIZATION
1050 | :BV THE PLAV MODULE (PLA1)

1220
1230
1240
1250

1046-

1049-

20 AC 11

1060
1070
1080

RPLA JSR PLA1
| AD 14 11 | | LDA STBL+14
104C- | 05 E3 | 1090 | CMP -LSTL
104E- | D0 02 | 1100 | BNE RPL1
1050- | E6 E9 | 1110 | INC -TPNT
1052- | 24 E2 | 1120 | RPL1 BIT -STUS
1054- | 30 0A | 1130 | BMI ROUT
1056- | A5 EC | 1140 | LDA -KBUF
1058- | F0 02 | 1150 | BEQ OLDK
105A- | 85 E4 | 1160 | STA -TTRN
1050- | A5 E4 | 1170 | OLDK LDA -TTRN
105E- | 85 E6 | 1180 | STA -TRNS
1060- | E6 E5 | 1190 | ROUT INC -CNTR
1062- | 60 | 1200 | RTS
| | 1210

CALL PLAV MODULE
WAS THE PREVIOUS MODE
MSAV (PROG. SCORE)?
NO-SKIP INCREMENT
INC. T-SEQ POINTER
T-SEQ ASSERTED ?
OPTION ON - LEAVE

OPTION OFF- GET NOTE

AND IF NO NOTE, BRANCH
SAVE NOTE FOR NEXT TIME

GET LAST ACTIVE NOTE
USE AS TRANSPOSE
INCREMENT TEMPO COUNTER

AND RETURN

SINGLE PLAV MODE - WAITS FOR AGO KEV THEN PLAVS SEQUENCE ONCE THROUGH TRANSPOSED TO INDICATED KEV

1063- | 90 04 | 1260 | SING BOO SNG1
1065- | A5 EC | 1270 | LDA -KBUF
1067- | D0 DD | 1280 | BNE RPLA
1069- | 20 46 10 | 1290 | SNG1 JSR RPLA
1060- | A5 EA | 1300 | LDA -MPNT
106E- | D0 0B | 1310 | BNE SRTN
1070- | A9 00 | 1320 | LDA 00
1072- | 85 E5 | 1330 | STA -CNTR
1074- | A6 E8 | 1340 | LDX *MEND
1076- | BD 01 03 | 1350 | LDA MTB1, X
1079- | 85 EB | 1360 | STA *PBUF
107B- | 60 | 1370 | SRTN RTS
| | 1380

FIRST PASS, BRANCH
AGO KEV DOWN ?
VES - PLAV SEQUENCE
NO - "PLAV" THEN RETURN
M-SEQ POINTER > 0 ?
VES - RETURN

NO - PREPARE
ZERO TEMPO COUNTER
POINT TO LAST NOTE
OF M-SEQ AND GET IT
PLACE IN PLAV BUFFER
THEN RETURN
1390 | UP TEMPO AND DOWN TEMPO - COMMON PORTION
1400 | OF BOTH PROGRAMS ON PAGE 2
1410 | :
107C- | A9 7E | 1420 UTMP | LDA 7E | THE OP-CODE FOR ROR
107E- | D0 02 | 1430 | BNE U/D | BRANCH ALWAVS
1080- | A9 3E | 1440 DTMP | LDA 3E | THE OP-CODE FOR ROL
1082- | 4C00 12 | 1450 U/D | JMP TCOM | JUMP FOR THE REST
1460 | :
1470 | REST MODE - EXTENDS NOTES OR UN-NOTES
1480 | WHEN IN PROGRAM EVENT MODE
1490
1085- | 18 | 1500 | REST CLC | PREPARE FOR ADDITTION
1086- | A5 E5 | 1510 | LDA -CNTR | GET TEMPO COUNTER
1088- | 65 El | 1520 | ADC -TPO | ADD TEMPO VALUE
108A- | 85 E5 | 1530 | STA *CNTR | PUT COUNTER BACK
108C- | A5 E3 | 1540 | LDA -LSTL | AND RETURN TO
108E- | 8D 7B 11 | 1550 | STA ACTN+01 | PREVIOUS OPERATING
1091- | 60 | 1560 | RTS | MODE
1570
1580 | STOP/STEP MODE - STOPS PLAV WITHOUT
1590 | CHANGING POINTERS. | SINGLE STEPS THROUGH
1600 | SEQUENCE
1610
1092- | B0 0E | 1620 | STEP BCS STP1 | NOT FIRST PASS-BRANCH
1094- | A9 FF | 1630 | LDA OFF | SET TEMPO COUNTER AT
1096- | 85 E5 | 1640 | STA -CNTR | "TIMED OUT" VALUE
FOLiJPHONy | November/December 1978 | 33

1098- | 28 86 11 | 1658 | JSR CONT | CALL PART OF PLAY MODULE
1098- | 8E 28 88 | 166S | STX DSP | DISPLAY M-SEQ POINTER
109E- | A9 80 | 1678 | LDR 00 | MAKE TRANSPOSE VALUE
10A0- | 85 E6 | 1688 | STA *TRNS | EQUAL TO ZERO
10A2- | 60 | 1690 | STP1 RTS | AND RETURN
1700
1718 | PROGRAM EVENT MODE - SAVES M-SEQUENCE
1720 | BUT SUBSTITUTES EVENT CLOCK FOR REAL-TIME
1730 | :CLOCK

1740
10A3- | 80 02 | 1750 | ESAV BCS ESI | FIRST PASS, | INITIALIZE
1085- | 85 E5 | 1760 | STA *CNTR | TEMPO COUNTER AS ZERO
10A7- | 20 84 11 | 1770 | ESI | JSR MSV1 | CALL SAVE MODULE
10AA- | A5 E5 | 1780 | LDA *CNTR | GET TEMPO COUNTER
10AC- | D0 05 | 1790 | BNE EOUT | NO ENTRY-RETURN
10RE- | 18 | 1800 | CLC | PREPARE
10RF- | 65 El | 1810 | ADC *TPO | ADD TEMPO VALUE
1081- | 85 E5 | 1820 | STR -CNTR | SAVE AS TEMPO COUNTER
10B3- | 60 | 1830 | EOUT RTS | THEN RETURN
1840
1858 | :OPTION MENU - RETURNS TO PREVIOUS
I860 | :OPERATING MODE AFTER TURNING ON OR
1870 | •CANCELLING OPTIONS
1880
10B4- | 85 E9 | 1890 | TBLM STR *TPNT | T-SEQ POINTER TO BEG.
1086- | A5 E2 | 1900 | LDR *STUS | ASSERT T-SEQ OPTION
1088- | 09 80 | 1910 | ORA 80
10BA- | D0 0E | 1920 | BNE MCOM | BRANCH ASLWAYS
10BC- | A5 E2 | 1930 | MET | LDR *STUS | TURN METRONOME ON
10BE- | 09 40 | 1940 | ORA 40
10C0- | D0 08 | 1950 | BNE MCOM | BRANCH ALWAYS
10C2- | A5 E2 | I960 | SYNC LDR *STUS | TURN ON SYNC TO
10C4- | 09 01 | 1970 | * ORA 01 | CLICK TRACK OPTION
10C6- | D0 02 | 1980 | BNE MCOM | BRANCH ALWAYS
10C8- | A9 00 | 1990 | CNCL LDR 00 | PREPARE AND
10CR- | 85 E2 | 2000 | MCOM STR *STUS | CANCEL ALL OPTIONS
10CC- | 4C 0F 12 | 2010 | JMP TOMI | JUMP FOR THE REST
2020
2030 | :CLICK MODE - SENDS CLICK TRACK TO TAPE
2040 | :AGO KEYBOARD SCAN RATE IS TIMER
2050
10CF- | 18 | 2060 | CLIK CLC | PREPARE TO SEND "0"
10D0- | 20 25 IE | 2070 | JSR SBIT | SEND IT
10D3- | 60 | 2080 | RTS | RETURN FOR KEYBOARD DELAY
2090
2100 :METRONOME TEMPO CHANGE - PROGRAM ON PAGE 2 2110
10D4- | 4C 54 12 | 2120 | TCHG JMP TCH | JUMP TO PROGRAM

2130
2140 :DUMP M&T-SEQ TO TAPE - PROGRAM ON PAGE 2 2150
10D7- | 4C 20 12 | 2160 | OTRP JMP TOUT | JUMP TO PROGRAM
2170
2180 •.LORD M&T-SEQ FROM TAPE - PROGRAM ON PAGE 2 2190
10DR- | 4C 33 12 | 2200 | iTrp jup tin | JUMP TO PROGRAM

2210
2268
2290 :COMMAND LINKS - LOW BYTE OF ADDRESS OF SUBS 2300

1100- 85 85 85 85 C2 BC B4 C8 1108- CF D4 80 7C DA D7 0C 00 1110- 45 92 63 46 3F A3 IE 46

2790
2800 | . OR 1118
2810
2820 | :COMMON PROGRAM - DOES METRONOME WHEN ON
2830 | ADDS PLAY AND TRANSPOSE BUFFERS TO GET
2840 | :OUTPUT NOTE, PLAYS NOTE, READS COMMAND
2850 | KEYBOARD AND JUMPS TO SELECTED MODE
2860 | •SUBSTITUTES CLICK SYNCH FOR KEYBOARD
2870 | :TIMING LOOP WHEN SYNC OPTION IS ASSERTED
2880
1118- | A5 E2 | 2890 | COM | LDA *STUS | CHECK OPTIONS
111A- | 48 | 2900 | PHA | SAVE A COPY
1118- | 0A | 2910 | ASL | MERONOME ON ?
111C- | 10 22 | 2920 | BPL COM0 | NO - BRANCH
111E- | C6 DF | 2930 | DEC *MTRC | DECREMENT METRONOME COUNTER
1120- | 10 IE | 2940 | BPL COM0 | NOT <0 YET, BRANCH
1122- | A6 El | 2950 | LDX -TPO | TIME UP, GET TEMPO VALUE
1124- | CA | 2960 | DEX | DECREMENT ONCE
1125- | 86 DF | 2970 | STX *MTRC | THEN SAVE AS COUNTER
3428 | :SAVE MODULE - TAKES CARE OF ALTERNATELY
1127- | 89 86 | 2980 | | LDA | ■TO i-ETERMiNE ALTERNATE DISPLAY
1129- | AA | 2990 | | rc;< | CYCLE AND "PENDULUM" LEFT
112A- | 18 | 3008 | | CLC | PREPARE FOR ADDITTION
112B- | 65 E0 | 3010 | | ADC *METF | ADD FLIP-FLOP VALUE
112D- | 85 E0 | 3020 | | STA -METF | SAVE NEW VALUE
112F- | 10 0C | 3030 | | BPL MET1 | ALTERNATE? - DISPLAY
1131- | A5 EB | 3040 | | LDA -PBUF | OTHERWISE, GET OUTPUT
1133- | 09 80 | 3050 | | ORA 80 | SET D7
1135- | 85 EB | 3060 | | STA -PBUF | SAVE IN PLAY BUFFER
1137- | 18 | 3070 | | CLC | PREPARE AND
1138- | 20 25 IE | 3080 | | JSR SBIT | CALL BEEP
113B- | A2 08 | 3090 | | LDX 08 | "PENDULUM" RIGHT
113D- | 8E 20 08 | 3100 | MET1 STX DSP | SHOW PENDULUM
1140- | A5 E6 | 3110 | COM0 LDA *TRNS | IS THERE A TRANSPOSE ?
1142- | F0 03 | 3120 | | BEQ COMI | NO - BRANCH
1144- | 18 | 3130 | TRAN CLC | YES - PREPARE
1145- | 69 A4 | 3140 | | ADC 0A4 | CALCULATE TRANSPOSE VALUE
1147- | 18 | 3150 | COMI CLC | MORE PREPARATION
1148- | 65 EB | 3160 | | ADC -PBUF | CALCULATE NOTE
114A- | 8D 40 08 | 3170 | COUT STA OUTP | PLAY NOTE
114D- | 68 | 3180 | | PLA | GET STUS (OPTION CODES)
114E- | 6A | 3190 | | ROR | SYNC OPTION ON ?
114F- | 90 06 | 3200 | | BCC KRED | NO - SKIP
1151- | 20 49 IE | 3210 | | JSR DBIT | WAIT FOR CLIK
1154- | 4C 6D 11 | 3220 | | JMP CTRL | SKIP READING AGO
1157- | 2C 10 08 | 3239 | KRED BIT KBD | WRIT FOR DUMMY SCAN
115A- | 10 FB | 3240 | | BPL KRED | LOOP UNTIL STARTED
115C- | AD 10 08 | 3250 | KR2 | LDA KBD | WAIT FOR SCAN TO START
115F- | 30 FB | 3260 | | BMI KR2 | LOOP UNTIL STARTED
1161- | 2C 10 08 | 3270 | KR3 | BIT KBD | CHECK FOR KEYS DOWN
1164- | 30 05 | 3280 | | BMI KRTN | WHEN SCAN DONE, RETURN
1166- | 50 F9 | 3290 | | BVC KR3 | CURRENT KEY NOT DOWN, LOOP
1168- | AD 10 08 | 3300 | | LDA KBD | KEY DOWN, GET IT
116B- | 85 EC | 3310 | KRTN STA *KBUF | SAVE RESULT
116D- | 20 00 IF | 3320 | CTRL JSR DECD | GET COMMAND
1170- | B0 06 | 3330 | | BCS DO | OLD COMMAND - DO IT
1172- | 89 00 11 | 3340 | | LDA STBL, Y | NEW COMMAND - GET LINK
1175- | 8D 78 11 | 3350 | | STA ACTN+01 | PLACE LINK
1178- | A9 00 | 3360 | DO | LDR 00 | THIS WILL BE HANDY
117A- | 20 03 00 | 3370 | ACTN JSR DUMY | CALL OPERATING MODE
117D- | AD 7B 11 | 3380 | | LDR RCTN+01 | SAVE CURRENT COMMAND
1180- | 85 E3 | 3390 | | STA *LSTL | LINK FOR LATER
1182- | D0 94 | 3400 | | BNE COM | AND LOOP ALWAYS
| | 3410

STACKING DURATIONS AND NOTES IN M-SEQUENCE USES WHAT WILL BE "END OF SEQUENCE-INDICATOR IN PLAY MODES AS POINTER

3430
3440
3450
1184- | B0 09 | 3460
3470 | MSV1 BCS MSI
1186- | 8D 01 03 | 3480 | | STA MTBL+01
1189- | 85 E8 | 3490 | | STA *MEND
118B- | 85 E6 | 3500 | | STA *TRNS
118D- | 85 EB | 3510 | | STA -PBUF
118F- | A5 E5 | 3520 | MSI | LDA -CNTR
1191- | R6 E8 | 3530 | | LDX -MEND
1193- | 9D 00 03 | 3540 | | STA MTBL, X
1196- | 20 13 10 3550 | JSR NRM1
1199- | 29 7F | 3560 | | AND 7F
1198- | DD 01 03 | 3570 | | CMP MTB1, X
119E- | F0 08 | 3580 | | BEQ OUT
11R0- | E8 | 3590 | | INX
11A1- | E8 | 3600 | | INX
11A2- | 86 E8 | 3610 | | STX -MEND
11A4- | 9D 01 03 | 3620 | | STA MTB1, X
11A7- | A9 00 | 3630 | | LDA 00
11A9- | 85 E5 | 3640 | | STA -CNTR
11AB- | 60 | 3650 | OUT | RTS
| | 3660

FIRST PASS?
YES-ZERO PROGRAM NOTE
ZERO M-SEQ POINTER
ZERO TRANSPOSE
ZERO OUTPUT NOTE
GET TIME SINCE LAST NOTE
AND M-SEQ END POINTER
SAVE THE TIME
IN CASE NO KEYS DOWN
CLEAR D7 IN OUTPUT NOTE
SAME AS LAST NOTE?
YES, LEAVE
NO, SAVE BY INCREMENTING
M-SEQ POINTER TWICE
AND SAVING RS END
THEN SAVE NOTE

AND ZERO TIME SINCE
LAST NOTE
RND RETURN

3670
3680
3690
3700

■PLAY MODULE - MANAGES M-SEQ AND T-SEQ :POINTERS AS WELL AS TEMPO CLOCK. :DETERMINES WHEN NOTES ARE TO BE PLAYED

UAC- | 80 08 | 3710 | PLA1 BCS CONT | FIRST PASS ?
11AE- | 85 E4 | 3720 | STA -TTRN | YES-ZERO TEMP. | TRANSPOSE
1180- | 85 E9 | 3730 | LP1 | STA -TPNT | ZERO T-SEQ POINTER
1182- | 85 EA | 3740 | LP2 | STA -MPNT | AND M-SEQ POINTER
11B4- | 85 E5 | 3750 | STA -CNTR | AND CLOCK (TEMPO CONTER)
1186- | A5 E5 | 3760 | CONT LDA -CNTR | GET CLOCK
1188- | A4 E9 | 3770 | LDY -TPNT | GET T-SEQ POINTER
11BA- | R6 EA | 3780 | LDX -MPNT | GET M-SEQ POINTER
11BC- | DD 02 03 | 3790 | CMP MTB2, X | TIME UP?
34 | PSUPHONU | November/December 1978

11BF- | 96 15 | 3866 | 885 51.1 | NO, BRANCH
1151- | R9 66 | 3816 | LDft 86 | VES, PREP | C0UN7ER, E70.
11C3- | 85 55 | 3326 | 57ft *CN7R | 50R NEX7 HCCUMULA7ION
11C5- | 58 | 3838 | INX | INGREMEN7 M-SEQ P0IN7ER
11C6- | 58 | 3846 | I NX | 7WI0E
UC7- | 86 5ft | 3856 | SIX *MPN7 | RND SAVE NEW P0IN7ER
11C9- | 54 58 | 3866 | CPX ENV | END 05 M-SEQ?
11CB- | V6 69 | 3876 | BN5 PL1 | NO - BRANCH
11CD- | 68 | 3888 | I NV | VES, | INC 7-SEQ P0IN7ER
HCE- | 64 57 | 3896 | CPY *7END | END 05 7-SEQ ?
11V6- | 86 V5 | 3966 | BCS LP1 | VES-S7RR7 7&M-SEQ AGAIN
11V2- | 84 59 | 3916 | 57V *7PN7 | NO-SAVE 7-SEQ P0IN7ER
1104- | V6 V6 | 3926 | BN5 LP2 | BRANCH-S7RR7 M-SEQ AGAIN
11V6- | 8V 63 63 | 3936 | PL1 | LDR M7B3, X | GE7 7HE N07E
11V9- | 85 58 | 3946 | 57ft *PBU5 | SAVE IN PLAV BUPPER
11VB- | 89 66 62 | 3956 | LDR 77BL,V | GE7 7RANSP0SE
11VE- | 85 56 | 3966 | 57ft *7RN5 | 70 7RANSP0SE BUPPER
1156- | 66 | 3976 | R7S | RE7URN
3986
3996 7APE 7RRNS55R PARAME7ER 7RBL5 4666
4616 7RP5 . H5 5538556358625862 4626
4636 | . OR 1268
4646
4656 | :COMMON P0R7I0N 05 7EMP0 UP & DOWN -
4666 | :R07A7ES RIGH7 OR LEP7 7HE DURA7I0NS
4676 | :SAVED WI7H M-5EQUENCE
4686
1268- | 8V 66 12 | 4896 | 7C0M 57ft PLftO | PLACE ROR OR ROL OP CODE
1263- | ft2 66 | 4166 | LDX 68 | ZERO A C0UN7ER/P0IN7ER
1285- | 18 | 4116 | 7LP | 0L0 | PREPARE
1266- | 75 62 63 | 4126 | PLRC ROR M7B2, X | R07A7E SAVED 7EMP0
1269- | 58 | 4136 | INX | INCREMEN7 P0IN7ER 7WICE
126ft- | 58 | 4146 | INX | 70 P0IN7 70 NEX7
1268- | 54 58 | 4158 | OPX *MEND | END 05 M-SEQ ?
126V- | V6 56 | 4166 | BNE 7LP | NO - LOOP FOR MORE
1265- | ft5 53 | 4176 | 70111 LDR *L57L | DONE, GE7 LINK AND
1211- | 8V 78 11 | 4186 | 57ft ftO7N+61 | 5E7 UP FOR PREVIOUS MODE
1214- | 66 | 4196 | R7S | 7HEN RE7URN

4266
4216 .SE7 UP PROOEDURE FOR 7APE 7RRNSPER 4226
1215- | R2 67 | 4236 | S77P LDX 67 | 7RRNSPER 7 BV7ES
1217- | 8V 51 11 | 4248 | S7P | LDft 7RPE, X | GE7 PARRME7ER PROM 7ABLE
121ft- | 95 56 | 4256 | 57ft *BUFP,X | PLACE IN P07-SH07 BUFFER
1215- | 6ft | 4268 | DEX | P0IN7 70 NEX7, MORE ?
121V- | V6 58 | 4278 | BNE S7P | VES - LOOP
1215- | 66 | 4286 | R7S | NO - RE7URN
4298
4366 :DUMP M-SEQ RND 7 -SEQ 70 7APE 4316
1226- | 26 15 12 | 4326 | 70U7 JSR S77P | SE7 UP FOR 7RANSPER
1223- | R5 58 | 4338 | LDH *MEND | SAVE M-SEQ END WI7H
1225- | 8V 66 63 | 4346 | 57ft M7BL | M&7-SEQUENCE
1228- | ft5 57 | 4358 | LDR *7END | ALSO 7-SEQUENCE END
122ft- | 8V 81 63 | 4366 | 57ft M7B1
122V- | ft9 vv | 4376 | LDR ODD | SE7 UP FOR DUMP
1225- | 26 46 12 | 4388 | JSR D07P | AND DO 17
1232- | 66 | 4398 | R7S | 7HEN RE7URN

4466
4416 LORD M-SEQ AND 7 -SEQ FROM 7RPE 4426
1233- | 26 15 12 | 4438 | 7IN | JSR S77P | SE7 UP FOR 7RANSFER
1236- | R9 11 | 4446 | LDR 11 | SE7 UP FOR LORD
1238- | 26 46 12 | 4456 | JSR D07P | AND DO 17
1238- | ftv 66 63 | 4466 | LDR M7BL | PLACE M-SEQUENCE END
1235- | 85 58 | 4476 | 57ft END
1246- | RV 61 63 | 4486 | LDR M7B1 | AND 7-SEQUENCE END
1243- | 85 57 | 4496 | 57ft *7END
1245- | 66 | 4588 | R7S | 7HEN RE7URN
4513
4526 :PER50RM 7fiPE 7RRNS5ER 4536
1246- | 26 ftft 15 | 4546 | D07P JSR OfiSS | CALL P07-SH07
1249- | ftv 65 11 | 4556 | LDft S7BL+65 | SE7 UP 70 RE7URN
1245- | 8V 78 11 | 4566 | S7R R07N+81 | IN NORMAL MODE
1245- | 18 | 4576 | OLC | PREPARE
1256- | 26 22 15 | 4586 | JSR BEEP | SIGNAL DONE
1253- | 66 | 4596 | R7S | AND RE7URN
4666
4618 :CHANGE ME7R0N0ME 7EMP0

## POUIPHONa

4620

1254- | 85 DF | 4638 | 7CH | S7A *M7RC | ZERO ME7R0N0ME CLOCK
1256- | 66 El | 4646 | | ROR *7P0 | HALVE 7EMP0 VALUE
1258- | 96 82 | 4656 | | BCC 7CHR | IF N07 ZERO, LEAVE
125A- | 66 El | 4666 | | ROR *7P0 | ZERO, MAKE N07 ZERO
125C- | D8 81 | 4678 | 7CHR BNE 7CM1 | GO SE7 UP PREVIOUS MODE

4686
| | 4696 | END | . EN
47Eia
NOTE: | The following is available
from PAIA | Electronics, | PO Box

# 14359, Oklahoma City, OK 73114:

# Seque 1.0 cassette data tape with

complete | documentation | and
plastic | computer | keyboard
overlay | $6.95 postpaid

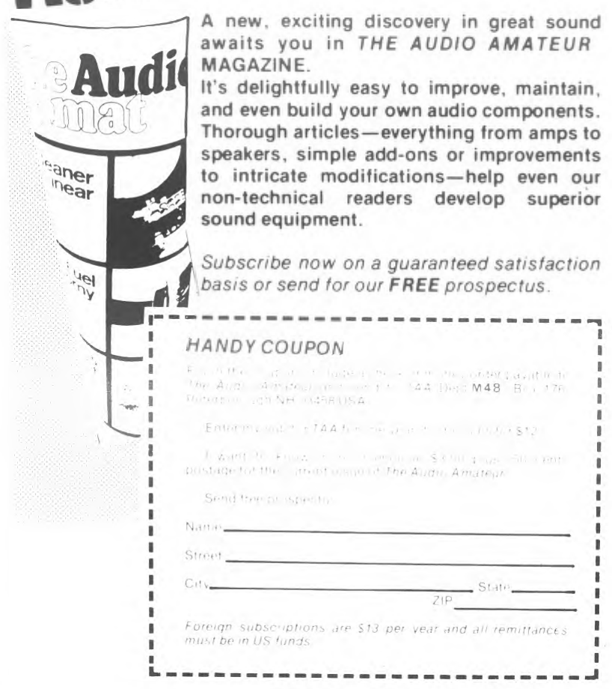
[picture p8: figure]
HANDY COUPON; \basis or send for our FREE prospectus.; awaits you in THE AUDIO AMATEUR MAGAZINE.; nontechnical; readers; develop; superior; sound equipment.

## Subscribe now on a guaranteed satisfaction

## A new, exciting discovery in great sound

It’s delightfully easy to improve, maintain, and even build your own audio components.

## Thorough articles—everything from amps to speakers, simple add-ons or improvements to intricate modifications—help even our

# MVKNMMM

November December 1978 | 35

# naP4700/J POLYPHONIC... Of Course!

# SYNTHESIZER/COMPUTER

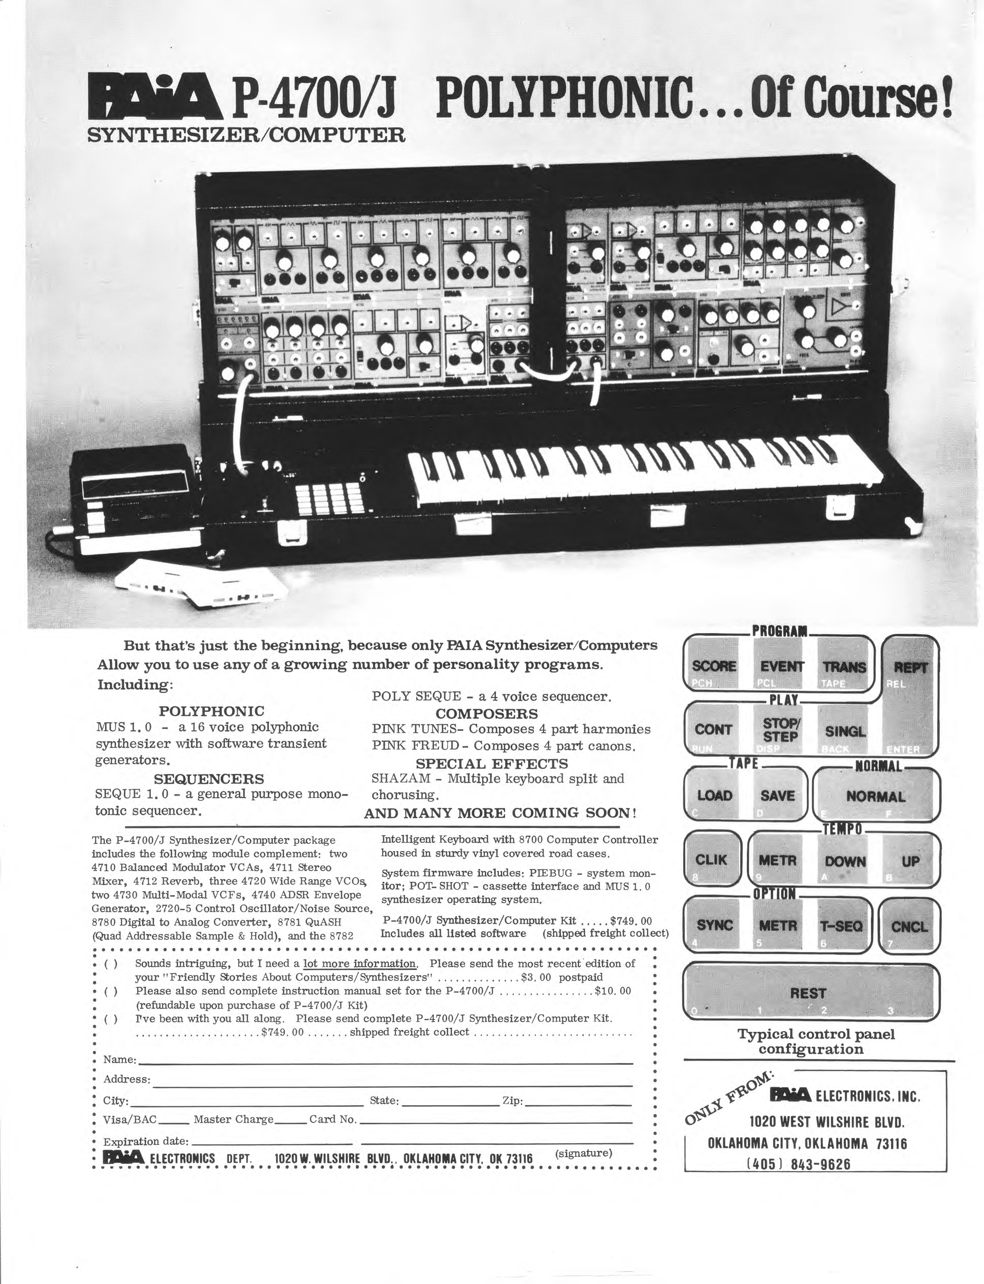
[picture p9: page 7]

## But that’s just the beginning, because only PAIA Synthesizer/Computers

Allow you to use any of a growing number of personality programs.

## Including:

## POLYPHONIC

# MUS 1.0 - a 16 voice polyphonic synthesizer with software transient

generators.

## SEQUENCERS

# SEQUE 1. 0 - a general purpose mono-

tonic sequencer.

POLY SEQUE - a 4 voice sequencer.

## COMPOSERS

# PINK TUNES- Composes 4 part harmonies

PINK FREUD - Composes 4 part canons.

## SPECIAL EFFECTS

# SHAZAM - Multiple keyboard split and

chorusing.

## AND MANY MORE COMING SOON!

The P-4700/J Synthesizer/Computer package includes the following module complement: two 4710 Balanced Modulator VCAs, 4711 Stereo Mixer, 4712 Reverb, three 4720 Wide Range VCO^ two 4730 Multi-Modal VCFs, 4740 ADSR Envelope Generator, 2720-5 Control Oscillator/Noise Source, 8780 Digital to Analog Converter, 8781 QuASH (Quad Addressable Sample & Hold), and the 8782

Intelligent Keyboard with 8700 Computer Controller housed in sturdy vinyl covered road cases.

System firmware includes: PIEBUG - system mon-itor; POT- SHOT - cassette interface and MUS 1. 0 synthesizer operating system.

P-4700/3 Synthesizer/Computer Kit | $749. 00
Includes all listed software | (shipped freight collect)
( ) | Sounds intriguing, but I need a lot more information. | Please send the most recent edition of
your "Friendly Stories About Computers/Synthesizers" | $3. 00 postpaid
( ) | Please also send complete instruction manual set for the P-4700/3 | $10. 00
(refundable upon purchase of P-4700/3 Kit)
( ) | I've been with you all along. | Please send complete P-4700/3 Synthesizer/Computer Kit.
$749. 00 | shipped freight collect

Name: _____ ____________________________________________________________________________________

Address:

City:State:Zip:

Visa/BAC | Master Charge | Card No

Expiration date:----------------------------------------------------------------------------------------------------------------------------------------------
na ELECTRONICS DEPT. | 1020W. WILSHIRE BLVD.. OKLAHOMA CITY. OK 73116 | (signature)

## Typical control panel configuration

o'A'
Vs | RWX ELECTRONICS. INC.
O^V | 1020 WEST WILSHIRE OLVD.
I

OKLAHOMA CITY. OKLAHOMA 73116
(405) 043-9626

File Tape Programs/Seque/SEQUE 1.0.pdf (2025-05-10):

„

# SEQUE 1.0

# UNIVERSAL IONOTONIC SEQUENCER

Now we're going to start a long discussion of sequencers.

lt's going to | be | long
because there is no single kind of sequencer that's best in every situation. Some will do better on stage and others will be more

at home in a studio setting. Polyphonie sequencers should at times be structured for storing and reproducing chord sequences while at other times each channel should be treated as a separate voice. The only really workable solution is to come up with an entire "family" of sequencers. The common limitation of all
programming | devices | currently
available is that none of them
can | offer | this | kind | of
versatility. | But, this is an
area where the system that we've developed, with its ability to
accept | a | wide | variety | of
personality endowing | programs,
will really come into its own. lf we need a studio sequencer (with click track synchronization and full score editing features, etc.) we can load that program;
when | a | chord | sequencer | is
required, that software can be loaded.
With few exceptions, these programs will all be "complete" in that once they are running, the system loses any "computer personality" that it may have had. All of the features that
the | program | off ers | will be
available with one or two touches
of | the | "command" | (computer)
keyboard. You can forget that the
computer's | there | because its
control | keys | are | dedicated
exclusively to functions assigned them by the program. "This key makes it play - this key makes it play faster." Easy.
To illustrate these points, we'll begin with a program called SEQUE 1.0, a monotonic sequencer

# REAL TIME MODES

written to run on a PAlA P-4700/C or its equivalent. lt can also be
easily patched to run | on | a
P-4700/J as outlined in the box. SEQUE 1.0 is an acceptable
"general | purpose" | sequencer
(acceptable from the standpoint of our new perspective - in terms
of the alternatives that | are
available | it | is | the | most
sophisticated | sequencer | ever
produced). | lt has some features
tailored for live performance and others that are primarily for studio use. The program listing and some additional notes appear in following pages.
COMMAND KEYS

When SEQUE 1.0
command | | keys

. © 1979 PAIA Electronics, Inc.

seem a little on the cryptic side. Let's look at function and begin by pointing out some of the ways that SEQUE 1.0 is different from what you're accustomed to.

PROGRAMMlNG A SEQUENCE

The first way that it's
different | is | that you don't
program it with knobs, you simply enter the note sequence from the AGO keyboard. More specifically the first operating mode that we'll examine is a completely "real time" performance mode. You simply touch the "PROGRAM SCORE" key and start playing. Except for the fact that we will be able to do much magic, the result is the same as if there were a tape recorder somewhere recording what you're playing. Whatever tempo you play in, including subtle timing nuances, are faithfully captured by SEQUE 1.0 and stored in the Computer memory. When you reach the point at which you want the sequence to repeat, touch REPEAT PLAY and it all comes back.

PLAYING THE SEQUENCE

Since this is a real time
mode, the timing of punching up REPEAT PLAY is important. If you were storing a repeating bass line, for example, you would play
the | single | figure | that
characterizes the bass line and then, at the exact point (and on the beat) where the first note of

the figure was to be repeated, touch REPEAT.
There -are other sequencers beginning to appear that operate this way, and if real music was played with droning bass lines

that repeat unchanged, endlessly, they would be perfectly adequate. And the music would be perfectly boring.
Not that real music doesn't
frequently | have | the
characteristic of a | repeating
bass figure, it does, but it's also made to sound different by
transposing | the | figure | into
different keys to follow | key
changes | in | the | composition.
While this fact seems to have been largely ignored by sequencer manufacturers, we don't have to settle for that.

TRANSPOSING

SEQUE 1.0 has a variety of provisions for transposing the
programmed | sequence. | The
simplest of these is that while in playback mode it can accept
information | on | key | changes
directly from the AGO keyboard. A little explanation.
Since we obviously want to be able to transpose both up and down in pitch, we need to decide
that | some | arbitrary | key
represents no transposition (play
the | sequence | as programmed).
SEQUE 1.0 assumes that the 2nd C
on | the | keyboard | is the "O
transpose" key. | keys up-scale
and down-scale from this one, then, represent transpositions up
and down | scale | respectively.
press the_ C# above the 2nd C , and the entire sequence plays with each note a semi-tone higher than was originally programmed. Press the F below the 2nd C and then each note plays a fifth lower.
As an example of this,
suppose that we were going to want to play a walking bass line as shown in figure 2.
Because of the things we've talked about already, it should· be relatively obvious that we only need to really "play" this much of the entire bass line:

t Repeat

(NOTE: Do not hit this note! Hit repeat at exactly the time you would have played it. )

Figure 3

because from then on it simply
repeats, | transposed | into
44

Figure 2
.. | .. | .. | II

Figure 4

different keys. As the riff from figure 3 plays, we can extend it out to the entire hass line simply by pressing keys on the
AGO keyboard to | perform | the
appropriate transpositions at the proper time. Like that shown in figure 4. Pretty exciting. And we really haven't even started yet.

THE TRANSPOSE SEQUENCE

While | being | able | to
transp9se the programmed sequence with real time keyboard entries will be plenty useful again and again, there are also going to be times when it will be at best a pain in the neck. You'll be busy doing other things. For these times, SEQUE 1.0 offers another feature, the ability to save a
programmed | sequence | of
transpositions.
Programming the T-sequence (as we'll call it) is just as simple as programming the melody sequence (M-sequence), you simply touch the PROGRAM TRANS pad and enter the sequence from the AGO keyboard. The major difference from a programming standpoint is that the T-sequence is a sequence of events, which is to say that it is not sensitive to the tempo
in | which | you | enter | the
information. | We'll | talk more
about EVENT sequences later. When the PROGRAM TRANS pad is first touched, it wipes out
any | previously | programmed
T-sequence and starts a new one. Each subsequent AGO | keyboard
entry | then | represents a key
change that the M-sequence will go through at the point at which it repeats.
During the programming of a T-sequence, the displays count to
show | where | we | are | in the
sequence, | and | the | note
corresponding | to | the

transposi tion will play while th·~ key is held down. When the key is
released, | the | note | stops
completely, so that there is no possibility of confusing this programming mode with others.
On playback, the M-sequence
will | be | played · | completely
through, transposed to the key signature corresponding to the
first | T-sequence | entry; then
completely through transposed by the second T-sequence entry, then the third, etc. When the end of the T-sequence is reached, the whole thing starts over again with the first note and the first T-sequence entry. To go back to
our | walking hass line for a
moment, the | T-sequence | would
program like this:

ad lib.

Q

Figure 5

In the terms which we will find most useful, enabling the automatic transpose is an OPTION which may be selected along with
one | or | more | of | the major
operating MODES. If we want to
assert | the | T-sequence option
during playback we do so | by
touching the T-seq. OPTION key. To stop the T-sequence and revert
to | the | manual | entry | of
transpositions, simply touch the OPTION CANCEL pad.
It is important to note that
canceling | the | T-seq. | option
simply | keeps the system from
invoking the T-sequence, and does not in any way alter the sequence as stored. You can turn the option on and off as many times during a set as desired.
And still there's more.

SINGLE PLAY
There will be times when we don't want the sequence to repeat endlessly, but simply to play one time through and stop. A SINGLE PLAY MODE.
An | important | diff erence between the two modes is that
whereas REPEAT begins playing the
sequence as soon | as | it | is
touched, SINGLE PLAY waits for an AGO key | to be pressed and then
plays.
The T-sequence option may
also be asserted in the SINGLE PLAY MODE, but it has been my
experience | that | it's | not
tremendously useful. | Much more useful is to have the T-seq.
option cancelled (which selects
the | AGO | keyboard | as | the
transposition source), so that pressing an AGO key not only starts the sequence playing, but causes it to play in the key selected.
Releasing the key which
initiated the sequence will not cause it to stop (once started it always plays to the end), but pressing a different key in the
middle of the | sequence | will
immediately transpose it to a new key signature.
| | TEMPO KEYS
The function of the TEMPO UP and TEMPO DOWN keys is just what you would expect. Touch TEMPO UP and the tempo of the sequence being played doubles. Touch it
again and the | tempo | doubles
again. | Touch TEMPO DOWN and the
tempo rate is divided in half. If not over-used, these two keys will increase and decrease
tempo | while | still | keeping
relative | timing | of | notes
unchanged; however, raising the tempo too high will cause some timing information to be lost and
will cause the notes | to | be
"jammed 11 | together | so | that
synchopation will change. Beware and be aware that this fact has special effects implications there may be times when you want to do just this.

TAPE SAVES AND LOADS

The TAPE pads control a couple of operating modes which
should also be useful. TAPE SAVE causes | the | M-sequence | and
T-sequence information currently in the computer's memory to be dumped to magnetic tape. when you come up with a "keeper" start your recorder going (recording) and touch TAPE SAVE. After a short leader and synchronizing tone is generated, the displays
will start to count and within a few | seconds | your | complete
composition will be stored as data on the tape Ca hint - always save things twice) | _ Loading a composition that was previously saved on | tape

consists of playing the tape and touching the TAPE LOAD command
pad. | As | with | the | saving
operation, the displays count as the data transfers from tape to memory. If, after loading a tape,
you punch up PLAY | MODE | and
nothing happens, it means that the load was unsuccessful. Try again with the second copy (and
review | the | "tape | selection"
section of PAIA's CS-87 POT SHOT manual).
NORMAL MODE
NORMAL is simultaneously the
most | straightforward | and
ubiquitous of all the operating
modes. NORMAL is nothing more than | a | normal | | monotonic
synthesizer | function, | the
important point is that asserting this mode of operation does not alter previously ~rogrammed M or T sequences. ~t simply ignores them as long as this mode is selected. at any time you can punch-up SINGLE or REPEAT PLAY and do that magic and with a touch of the NORMAL pad be back to plain synthesizer.
SUBTLETIES AND TRICKS
lt | seems | to me that a sequencer for use on stage should
have two major design goals: | it
should be easy to program and
operate | | (which | SEQUE | 1.0
certainly | is) | and it should
enable the user to do a better job of the thing he's there to do - put on a show. As theatrical a show as possible. SEQUE 1.0 has

several of these "show" features. The ability to shift back
and forth between the various
modes | of | operation | (and
specifically the availability of the NORMAL mode which doesn't mess up programmed sequences) is definitely one of these.
Others are less obvious, for example:
When you have the T-sequence
option | selected | (so | that
transpositions come from their programmed sequence) and you go directly from the PROGRAM SCORE.

mode to REPEAT PLAY.without first asserting another operating mode, the first entry of the T-sequence will be skipped and the melody
sequence | will | begin | playing
immediately transposed by | the
second entry in the Transpose Sequence.
Why?
Because, when you entered
the characteristic sequence it was equivalent to | its | being
played the first time through (which would have been done using:.
the first | T-sequence | entry).
When you hit REPEAT PLAY and the computer takes over, it is in effect playing the sequence the second time - which should be done in the key of the second T-sequence entry.
The major application here is to allow you to enter (during set-up and tuning) a T-sequence for the number that you are going to be doing and then enter the
actual | | sequenced | | figure
extemporaneously. We all know how great it is when the magic is working and everybody's really cooking. This feature allows your automation equipment to tap
into | that | energy | and | the
innovation | that | frequently
results from it.
If for some reason you don't want to skip the first T-sequence entry, you simply terminate the PROGRAM SCORE mode with a command other than REPEAT PLAY (NORMAL, for instance; or SINGLE PLAY), then punch into REPEAT PLAY. Remember always, though, that the termination of PROGRAM SCORE mode must be done "in tempo" 1f the timing of the playback is to be correct.
Here's | another | special
application:
In | most | cases, | the
M-sequence is reserved for the melody, but the UP TEMPO command allows ·you to enter some short riff (live, yet) then speed the sequence up to the point that it has the effect of being a "voice"
of its own. | By then punching
into | SINGLE | PLAY | mode, the
sequence can then be used as you would a single note, which you
"play" | by | transposing | it.
Naturally, | the | T-seq. option
should be cancelled for this. And another:
REPEAT PLAY mode always
starts the M and T sequence from the beginning, making it any easy n;iatter to use the first few bars of the sequence again and again, for introductions, bridges, and special effects.

. '

Now we turn our attention to
the | studio-oriented | options
offered | by | this | "universal"
monotonic sequencer program. Some of the distinctions
between stage and studio use are somewhat arbitrary.
For example:

EVENT PROGRAM

The real-time SCORE melody programming mode that we examined in the first section of this piece can obviously be used in a recording studio as well as it can on stage, providing that

you're interested in recording only those things that are within
the | limits | of your physical
abilities. But the real promise of a small studio (or a big one, for that matter) is that it allows us to produce music that we don't have the chops to do in
real | time. | After | all, | not
everyone has the hours per day that it takes to gain physical mastery of a keyboard - but that doesn't mean that we don't have valid musical ideas, only that we need a little help in expressing them.
If a recording studio is a single thing, it's a time machine that allows days or weeks of work to be compressed into a few minutes of music. One of the programming modes that we have available (EVENT) is specifically designed to operate in this type of time-compression environment. In this mode we enter the music not so much as a melody, but as a series of notes and rests. A series of events which, when reproduced by the computer, turn out tobe a melody (maybe). There is of course nothing new about this mode of operation, this is the way sequencers have always worked. About the only new part is that instead of entering the events as positions of a knob or a series of numbers, we have an AGO keyboard on which to program.
Touching | the | command
keyboard's PROGRAM EVENT pad puts us in this programming mode. (See
Figure 1.) Melody | lines | are
entered much as they were with the SCORE mode, except that the computer is no longer watching for how long we hold a key down

# STUDIO IODES

or how rapidly the notes are played. It is now only interested in whether a key is up or down.
One | of | the | major
implications | of this is that
notes in the melody are "jammed" together in time, and on playback will come out exactly equally spaced, one note per beat. While this is OK in some cases, as a general rule it is unacceptable; because it is unacceptable, we have a REST pad on the command keyboard. The REST pad provides for syncopation. It is a means of "extending" an event so that it takes more than a single beat. If you're familiar with the operation of the rest key on
something | like | PAIA's
Programmable | Drum | Set, | you
already have a good idea what's going on, but there still are some surprises here.
Your first thought may be
that when you press and release a key on the AGO keyboard, that

constitutes an event. Actually, it's two events as far as SEQUE 1.0 is concerned - the first when the key was pressed and the next
when it | was | released. | It's
important to keep in mind that the REST pad can extend either of
these events. | ~~~
For example, this simple
phrase:

# ~~1 jJJj J

Figure 6
would | be | entered | from | the
keyboard by | pressing | F | and
releasing, press A and release,
press C, | release, | press | D,
release, | press | F | and while
holding the F key down, hit the REST block on the keypad, release the F key, tap the REST block, play A, touch the rest block before letting up the A key, release the key, and hit the rest block once more. The measure is now completely entered, and may be played by using the REPEAT or SINGLE keys as described last time. Note particularly that on the fifth note (the second F) where we wanted to extend the note to a full beat, the REST pad had to be touched twice; once to extend the "key down" event and again to extend the "key up" event.

At first, having to enter
two RESTs when we actually want to extend a note f or a single beat may seem a pain in the neck
(undeniably, it is) | but | the
slight inconvenience buys us a number of things. For example, the ability to slur notes.
In the above example, the D could have been slurred into the F by first touching the REST p:id before releasing the D key. This will lengthen the note to occupy the time normally used when the key is released. Then press the F key before releasing the D. This will cause the D to be entered in the next time slot without any articulation (triggering). Now, while holding the F key, touch the REST pad to lengthen it to a quarter note as covered earlier. After releasing the key, enter the additional REST required and proceed as usual.
Having | each | REST | pad
activation correspond to a "half" event (kind of) also allows us to
produce | dotted | notes as the
exceptions that they are rather than having to make specific tempo provisions for them which must be carried over to all notes in the sequence.
It | is | also possible to
generate | articulation | changes
whenever | a | note is extended
beyond a basic "dual" event. If', f'or example, you are generating a series of' notes where each note uses a key depression plus a REST and a key release plus a REST (f'our events), theses notes can be performed in three different manners. If entered as listed above, the note has equal time allotted for note perf'ormance and release. For a staccato style, the note could be entered with a key depression, release, and then two RESTs. For legato styles, the two RESTs could be entered while the key is held down, yielding three "on" events and one "of'f" event. Each of the above would occupy the same execution time
during | playback, | but | would
reflect | the | different
articulation styles.
Once the melody is in the
computer's memory, it makes no difference whether it got there with SCORE or EVENT programming modes as far as the playback and options are concerned. All of these features (real time or programmed transpositions, single or repeat play, tempo up and down, and tape saves or loads, etc.) work the same.

CLICK TRACK SYNCH

Even more powerful in the
studio than the EVENT programming mode are the features added by two other command pads; CLIK and (in the option box) SYNC. These provide a means of synchronizing
multiple tracks | of | sequencer
operation.
Once | you | start using a
sequencer for | recording, | you
begin | to find more and more
places where it can be used to relieve a lot of tedium. The problem in the past has been that
it | is, | for | all | practical
purposes, impossible to manually synchronize a sequencer to a track that's already on tape. Even slight differences in tempo soon build up to an intolerable variation in when a note is supposed to happen and when it actually does happen. Maybe there are people who could manually twiddle a tempo knob and keep
things | locked | together, | but
that's a hassle.
Most of us are familiar with
the | classical | "click | track"
approach | in | which | a
metronome-like "tick" is recorded on one track of a tape so live musicians can easily maintain the tempo of the original work in over-dubs. Our CLIK and SYNC command pads are simply this old concept extended into the realm of automation.
Touching the CLIK pad causes SEQUE 1.0 to begin producing a very rapid series of "clicks" that are machine readable and represent a standard clock rate which the SYNC option can read and synchronize to. The click appears at the normal cassette
output | jack | (where programs,
etc., that are to be saved to tape come from) and when using this option, this output is tied to one of the channels of the tape recorder on which you're recording your audio tracks.
To | use | the click track
option, the tape that you will be recording and mixing your audio onto must always be prepared first; you can't record a lead part and then come back and lay down the click, it won't work like that. Before doing anything else, connect the 8700's cassette output to the input of one track of your recorder, start the tape rolling in record mode, and after
allowing a | comfortable | quiet
leader, punch the CLIK pad. Allow the tape to run much langer than you think you'll ever need for
what | you're | going | to | be
recording, one thing you don't want to do is run out of click in the middle of things.
Synchronizing to the click track is simply a matter of connecting the output of the tape channel that contains the click to the normal cassette input jack of the computer, but note that some Juggling of the record and playback levels of this channel may be necessary for the computer to properly write and read the channel. In many cases, unless
your | recorder | is capable of
providing | very | high | outputs
(similar to the earphone levels from the cassette recorders which the computer was designed to work with), you may need to use a small external amp to provide the extra gain and current drive required. If your SYNC fails to respond, try using the earphone jack signal usually provided on multi-track recorders. If this doesn't provide enough power, try using a small portale practice amp (such as a Pygmy or Pignose)
whose earphone | output | should
adequately | drive the cassette
input jack of the computer. Assuming that you have some rhythm sequence (ordinarily the

first laid down) in the computer memory and that you're getting ready to record it as audio, proceed by first punching into the T-SEQ option (if you plan to use it) then touch the SYNC control pad. Roll the tape with the click track channel set to playback and the audio going to one of the other tracks which is naturally in record mode. Before the quiet leader ends, touch the REPT/PLAY command pad and hold it. When the click track starts, so will the sequence. When enough
of the track is | laid | down,
terminate | the | play | mode by
touching the NORMAL pad.
lt is necessary to select
the SYNC OPTION last in the above sequence of events because once this option is asserted, a click track must be coming in on the cassette port for the computer to recognize any further commands. If you find yourself with a "dead" computer caused by CLIK being selected with no click track present, you can either run a tape which has a click track or reset the computer and run the program again.
In | situations | where the
sequence is not to be played from the first down-beat, the SYNC OPTION should be enabled before rolling the tape and REPT/PLAY punched in when the time comes for the sequence to start.
A little constructive play
will | go | a | long way toward
familiarizing | you | with | the
capabilities | of this powerful
option. Here are some we haven't mentioned yet:
You have probably already
noticed the somewhat cryptic METR designations that appear in both
the | OPTION and TEMPO control
boxes. | And | probably | you've
figured | out | that | it | means metronome (a handy thing in any

studio). But this is kind of a super metronome because not only does it ha:ve a "pendulum" (which shows in the computer's twin displays) and an audible click (which you hear from the beeper)
but | it | also | provides | an
electrical output in the form of a short positive going pulse that appears as D7 of the D/A output channel (which in turn shows up on the Flag 2 pin jack of the D/A's front panel). This pulse is
enormously | useful | in
synchronizing external devices (a
Programmable | Drum | Set, | for
example).
Since both the SYNC and METR options may be asserted at the same time, the external device can be synched to a pre-recorded audio track.
The METR pad in the TEMPO
control box is obviously the tempo control for the metronome. Like the other tempo controls that we looked at last time, this one works in octaves. Each time

the pad is touched the metronome tempo doubles until the maximum rate is reached, then the next touch causes the tempo to "fold back" to the minimum rate.
lt may be somewhat out of
sequence (?) to mention here that the tempo of the metronome is the tempo at which sequences stored in EVENT mode will play back, though of course, the TEMPO UP and DOWN command pads will also alter the tempo of the sequence once saved, as outlined last time.
Another | point | When
electrically synchronizing things to the click track, the METR TEMPO can still be varied to accomodate different timings, and since it operates by octaves the

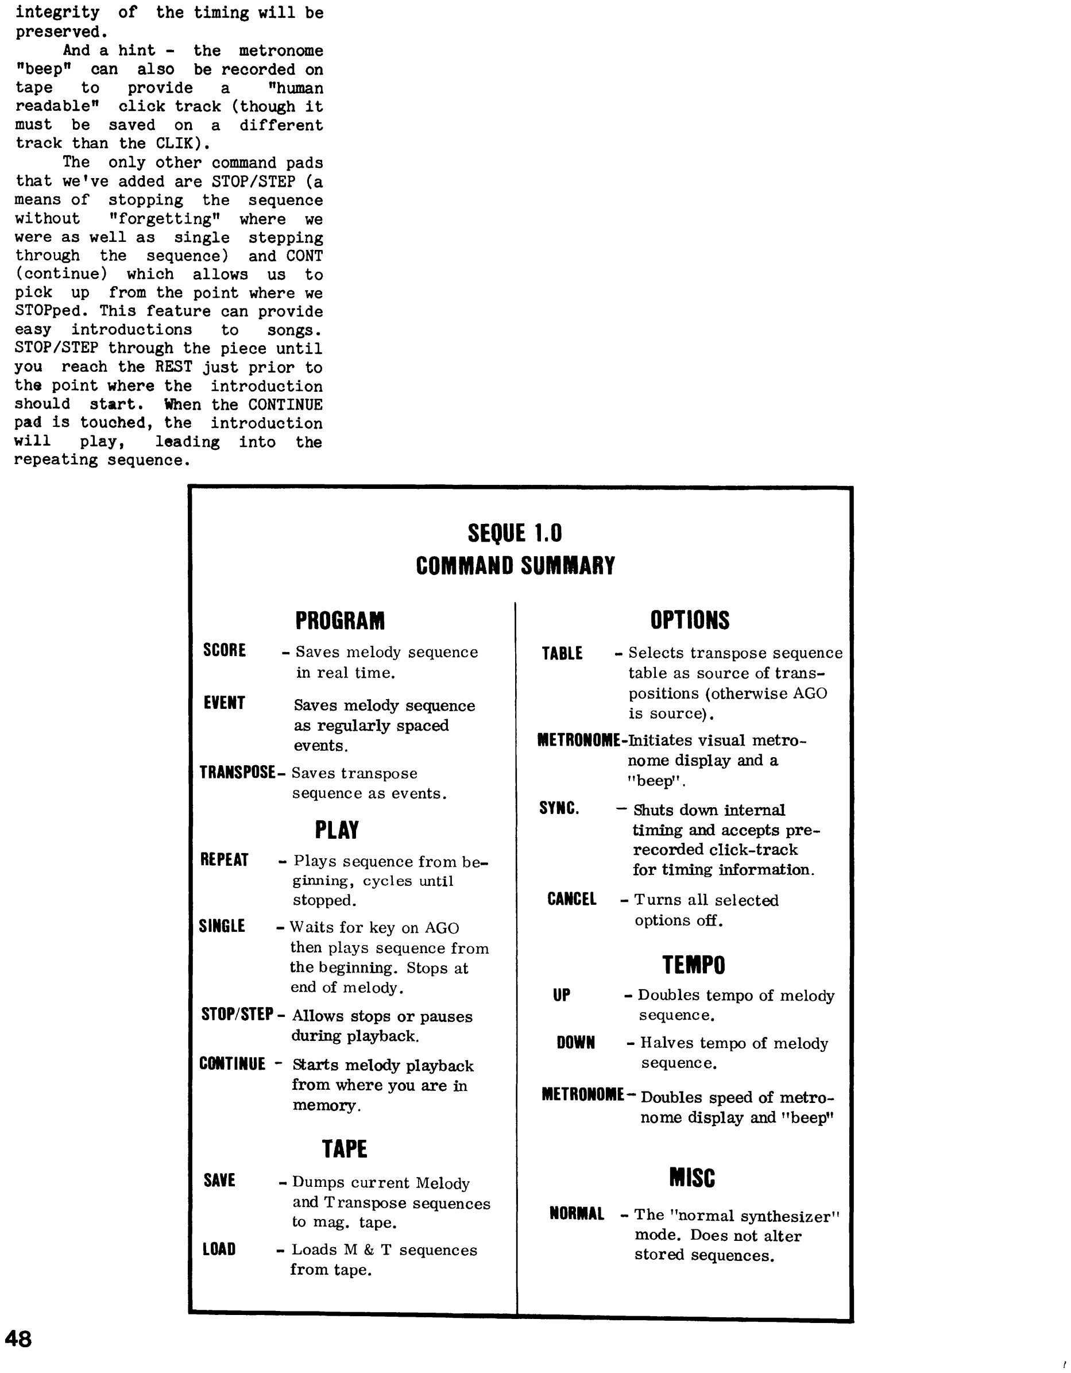
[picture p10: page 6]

integrity of the timing will be preserved.
And a hint - the metronome "beep" can also be recorded on
tape | to | provide | a | "human
readable" click track (though it must be saved on a different track than the CLIK).
The only other command pads that we've added are STOP/STEP (a means of stopping the sequence without "forgetting" where we were as well as single stepping through the sequence) and CONT (continue) which allows us to pick up from the point where we STOPped. This feature can provide
easy introductions | to | songs.
STOP/STEP through the piece until you reach the REST just prior to the point where the introduction should start. When the CONTINUE pa4 is touched, the introduction
will | play, | leading into the
repeating sequence.

## SEQUE 1.0 COMMAND SUMMARY

SCORE

EVENT

## PRO GRAM

- Saves melody sequence
in real time.
Saves melody sequence
as regularly spaced
events.
TRANSPOSE- Saves transpose sequence as events.

## PLAY

REPEAT | - Plays sequence from be- ginning, cycles until stopped.
SINGLE | - W aits for key on AGO then plays sequence from the beginning. Stops at end of melody.

STOP/STEP - Allows stops or pauses
| during playback.
CONTINUE - starts melody playback
| from where you are in memory.

SAVE

LOAD

## TAPE

- Dumps current Melody
and T ranspose sequences
to mag. tape.
- Loads M & T sequences
from tape.

TABLE

## OPTIONS

- Selects transpose sequence table as source of transpositions (otherwise AGO
is source).
METRDNDME-Initiates visual metronome display and a
"beep".
SYNC. | - Shuts down internal timing and accepts pre- recorded click-track for timing information.
CANCEL | - Turns all selected options off.

## TEMPO

UP | - Doubles tempo of melody
DOWN | sequence.
- Halves tempo of melody
| sequence.

METRONOME - Doubles speed of metro-
| nome display and 11 beep"

## MISC

NORMAL - The "normal synthesizer"
| mode. Does not alter stored sequences.

# LOADING SEOUE 1.0

LOADING FROM TAPE
Because part of the SEQUE 1. 0 program is held on the same page that the 6502 processor uses as a stack register, some very slight preparation is required before the SEQUE
1. O tape can be loaded. Specificly the stack pointer which is used by the PIEBUG monitor program and the stack pointer associated with the applications program must be set to assure that the stack will not over-write the program. And, as long as we are setting the stack pointer, the status register may as well be set to a known state.
These objectives may be met by these keyboard manipulations:
0-0-E-D-DISP-F-F-ENT | this sets the monitor stack
O-O-F-E-DISP-F-F-ENT-0-0-ENT this sets the user stack
| and status register.
On the tape supplied, SEQUE 1. 0 is saved with the identifier 01; and should be loaded to memory from location $0000 to $0280 using this entry sequence: 0-0-0-0-0-2-8-0-0-1-l-1-TAPE
The program is saved in triplicate so if the first copy won' t load for some reason you can always try for the next. All copies have the same identifier 01. If you experience continued difficulties in loading, refer to the POT-SHOT cassette Interface manual.

HAND LOADING
If you are absolutely unable to load the program from this cassette, return it for a replacement. Since transit time back and forth may present unbearable delays, you may consider hand-loading the program and dumping your own tape ( which goes a long way toward eliminating any problems caused by differences in tape recorders). To assist you should this solution become desirable, a hexadecimal dump of SEQUE 1. O is provided below. NOTE that even ifyou hand load the program, the stack and status register setting manipulations outlined above should be performed before
you start loading the program. | ---
With the stack pointers and status register set, the program may be hand loaded as outlines in the various 8700 manuals:

First the programming on page 0: 0-0-0-DISP-A-9-ENT-O-O-ENT-8-5-ENT- (etc.) Then page 1:
1-0-0-DISP-8-5-ENT~l-O-ENT-8-5-ENT- (etc.)
And finally page 2:
2-0-0-DISP-8-D-ENT-0-6-ENT-1-2-ENT- (etc.) Note that none of these blocks go all the way to the end of the page.
When done loading, immediately save the program to tape from $0000 to $0280. Do this before running the program to avoid the unpleasant experience of having some incorrectly copied code wipe out the program. Next verify the program by stepping through it and comparing memory con-tents to the hex dump. Finally, when you' re sure that it' s enteredcorrectlyandhavea copyontapejustincase, run it. RUNNING THE PROGRAM
Location 0 is both the hard start and the soft start location for this program.
0-0-0-0-RUN.
If the program crashes (as perhaps when SYNC is selected with no synchronizingtapeinput) it may be re-started from this same location without losing any melody or transposing sequences that had been saved to that point. Re-starting from this location will cancel any options which may have J:ieen selected and will cause SEQUE 1. o to come up in its NORMAL mode.

RUNNING SEQUE 1. OON A P-4700/J
SEQUE 1. 0 may easily be modified to run on a polyphonic system (though it will still be a monotonic sequencer) simply by changing the address of the output port which appears at SEQUE 1. O locations $14B & $14C. Changingthis address to $09FF will cause the output to appear at QuASH channel#t. This may be accomplished as follows: 1-41B-DISP-F-F-ENT-0-9-ENT
If you make this change, you should also save the altered program to tape.
A fully documented assembler listing of SEQUE 1. O starts on the following page.
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

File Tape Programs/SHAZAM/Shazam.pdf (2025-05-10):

Here is a program for all
you keyboardists out there who
want | to | experience | the
flexibility that a microprocessor provides. SHAZAM 0.1 is my first version of a keyboard operating system consisting of a package of
programs that provide | various
personalities | for | your | 8700
controlled | synthesizer. | The
programs | are | John Simonton’s
POLY, | and my own CHORUS | and
SPLITZ.
CHORUS is a general purpose,
monophonic | sequential | (or
circular) | assignment in | which
successive notes are assigned to
successive output channels | in
sequential | order | (sequential
assignment) until all available

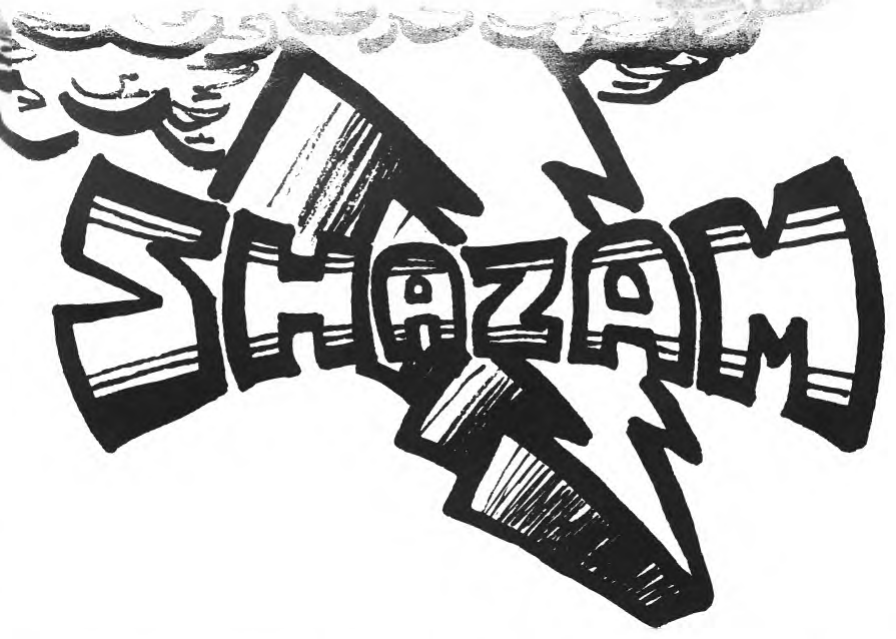
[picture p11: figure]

## (or "Maestro, a little software, please”)

By: Bob Yannes
voices are used, in which case the assignment wraps around to the beginning again (circular).
The unique | feature | of | this
routine | is that it allows notes
to continue decaying | on | one
channel while the new channel is playing (even if you hit the same key several times). This produces a rich pseudo-reverb or chorusing
effect that | greatly | enhances
monophonic | brass | and | string
patches. | The | problem | with
ordinary monophonic synthesizers is that if you play too fast and
don’t | allow | the | envelope
generators to reset, | the attack
portion | of | the | envelope is
bypassed which can totally ruin string sounds (ie: instead of a slow swell, your violins become percussive and go ’’BONG’’). While the sequential assignment helps reduce this problem, the amount of reduction is dependent on how many voices you have (the more the better) and how fast you play. In general, the more voices you have, the longer you can make the final decay on each voice and still use slow attacks. CHORUS also has some other features which I’ll cover in detail later. SPLITZ is a general purpose keyboard splitting program which allows you to split the keyboard
up arbitrarily into | as | many
voices | as | you | have | (or
want).While this is best utilized
with larger keyboards, | I still
find | it | useful | on my three
octave. The important thing to note is that you are free to place the split points wherever you want and make the split sections of the keyboard as short or as long as you want (thanks to our friend, the microprocessor). A split keyboard is useful for
playing | polyphonically | with
different patches on each voice. I’m sure that those of you who
have | tried | to | coordinate
different patches while running
POLY | have | found | it | a bit
difficult. The problem is that your timing must be exact when pressing the keys down, or your bass line will come out as a soprano patch and while your mind
is trying to sort | out | what
happened | (and that can take some
time if you’re playing a complex
polyphonic | passage) | POLY will
continue to assign things wrong until you straighten it out. This isn’t a fault of the algorithm, just human imprecision, but it only has to happen once to ruin a live performance. With SPLITZ, I use a brute force approach to
overcome | this | problem. | The
keyboard | is | split | up | into
various, | non-interacting
sections, | with | each | section
always being assigned to its own
output | channel. | The | program
doesn’t care when you play a note relative to other keys, if you
play within a | certain | split
section, that note will always be
assigned | to | the same output
channel. If you had a five octave
keyboard, | you could elect | to
split the keyboard up into five octaves, with each octave being assigned to its own voice. You could then patch the synthesizers up in order—channel one with a
bass | patch, | channel | two with a
lead patch, channel three with a
counterpoint, | etc. While this is
flexible and | allows | you | to
coordinate | a large number of
different | voices, | you | must
remember | that | the | split up
keyboard is rather small now | (in
the previous example, you would be limited to playing in only one octave for each voice) and even with the ability to separately transpose each voice this is a pretty big limitation, hence the program lends itself best to a few large splits (like on STRINGZ & THINGZ, you could split your keyboard to provide an octave of
cellos | and | two | octaves | of
violins). A popular set-up would be to give yourself an octave of synthesizer bass and two octaves of lead line patch, that way you can play your bassline without having to buy a new keyboard. CHORUS, SPLITZ and POLY are tied together as a single package
and use the 8700 | keyboard to
provide | a tuning function, | a
clear | function | (for | removing
transpositions, | glide or wrong
channel | assignments) | and | to
select | any one of the three
programs (while in one program it is possible to jump to either of the other two at the touch of a button). One nice feature of this
is that you can jump | to any of
POLJPHONy | November/December 1978 | 13
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

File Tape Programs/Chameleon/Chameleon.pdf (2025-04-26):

# an expandable control system for computer assisted synthesizer

# CHAMELEON 0.25

# BY JON BALLERAS ------------------------

There’s | little | telling | into | whose hands digital music
gear is falling and how it’s being used. | Some | users | running
digital control type systems undoubtedly have been programming
for | years | and | are contentedly typing in their own intricate
software, filled with stacks happily being pushed and | pulled,
indexes that know just where they're going and what to do when
they | get | there, | subroutines | nesting | comfortably | inside
subrouting, | and | God | knows | what | else. | Others, | like | me,
soldered up an 8700 without knowing a bit from byte, much less
being able to add $2 and $2 on the machine. | Worse, users like
me | can | easily | develop | propensity | toward | software
dependency—we become listing junkies | anxiously | waiting | the
next | hit | of | code | from | Simonton | or | some | other | kindly
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

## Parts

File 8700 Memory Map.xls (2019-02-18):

Bank | Address | Dir | Name | Enable | Description | Header | High | Mid | Lo Nyble | Addr Line | Bank Size | Size | Type
0x000 |  | IO | RAM |  |  |  | 0000 | X | X |  | 1024 | 2048 | RAM
0x400 |  |  | Unoccupied |  |  |  | 0100 | X | X |  | 1024
0x800 | 0x800 |  | ? |  |  |  | 1000 | 0000 | 0000 |  | 1 | 512 | IO
0x800 | 0x801 | In | Keyboard1 | CS0 | Keys 0-7 | J3 | 1000 | 0000 | 0001 | 0 | 1
0x800 | 0x802 | In | Keyboard2 | CS1 | Keys 8-F | J3 | 1000 | 0000 | 0010 | 1 | 2
0x800 | 0x804 | In | Keyboard3 | CS2 | Control keys | J3 | 1000 | 0000 | 0100 | 2 | 4
0x800 | 0x808 | In | Input 2 | CS3 |  | J5 | 1000 | 0000 | 1000 | 3 | 8
0x800 | 0x810 | In | Input 1 | CS4 |  | J4 | 1000 | 0001 | 0000 | 4 | 16
0x800 | 0x820 | Out | Display | CS5 |  |  | 1000 | 0010 | 0000 | 5 | 32
0x800 | 0x840 | Out | Outport | CS6 |  | J2 | 1000 | 0100 | 0000 | 6 | 64
0x800 | 0x880 | Out | Strobe | CS7 |  | J1 | 1000 | 1000 | 0000 | 7 | 128
0x900 |  | IO | Cassette | CS9 |  | J9 | 1001 | X | X | 8 | 256
0xA00 |  |  | Unoccupied |  |  |  | 1010 | X | X | 9 | 256 | 512 | N/A
0xB00 |  |  | Unoccupied |  |  |  | 1011 | X | X |  | 256
0xC00 |  | In | ROM0 |  |  |  | 1100 | X | X | 10 | 256 | 1024 | ROM
0xD00 |  | In | ROM1 |  |  |  | 1101 | X | X |  | 256
0xE00 |  | In | ROM2 |  | Cassette Code |  | 1110 | X | X |  | 256
0xF00 |  | In | ROM3 |  | Monitor(PIEBUG) |  | 1111 | X | X |  | 256
0xFFF |  | In | ROM END |  |  |  | 1111 | X | X

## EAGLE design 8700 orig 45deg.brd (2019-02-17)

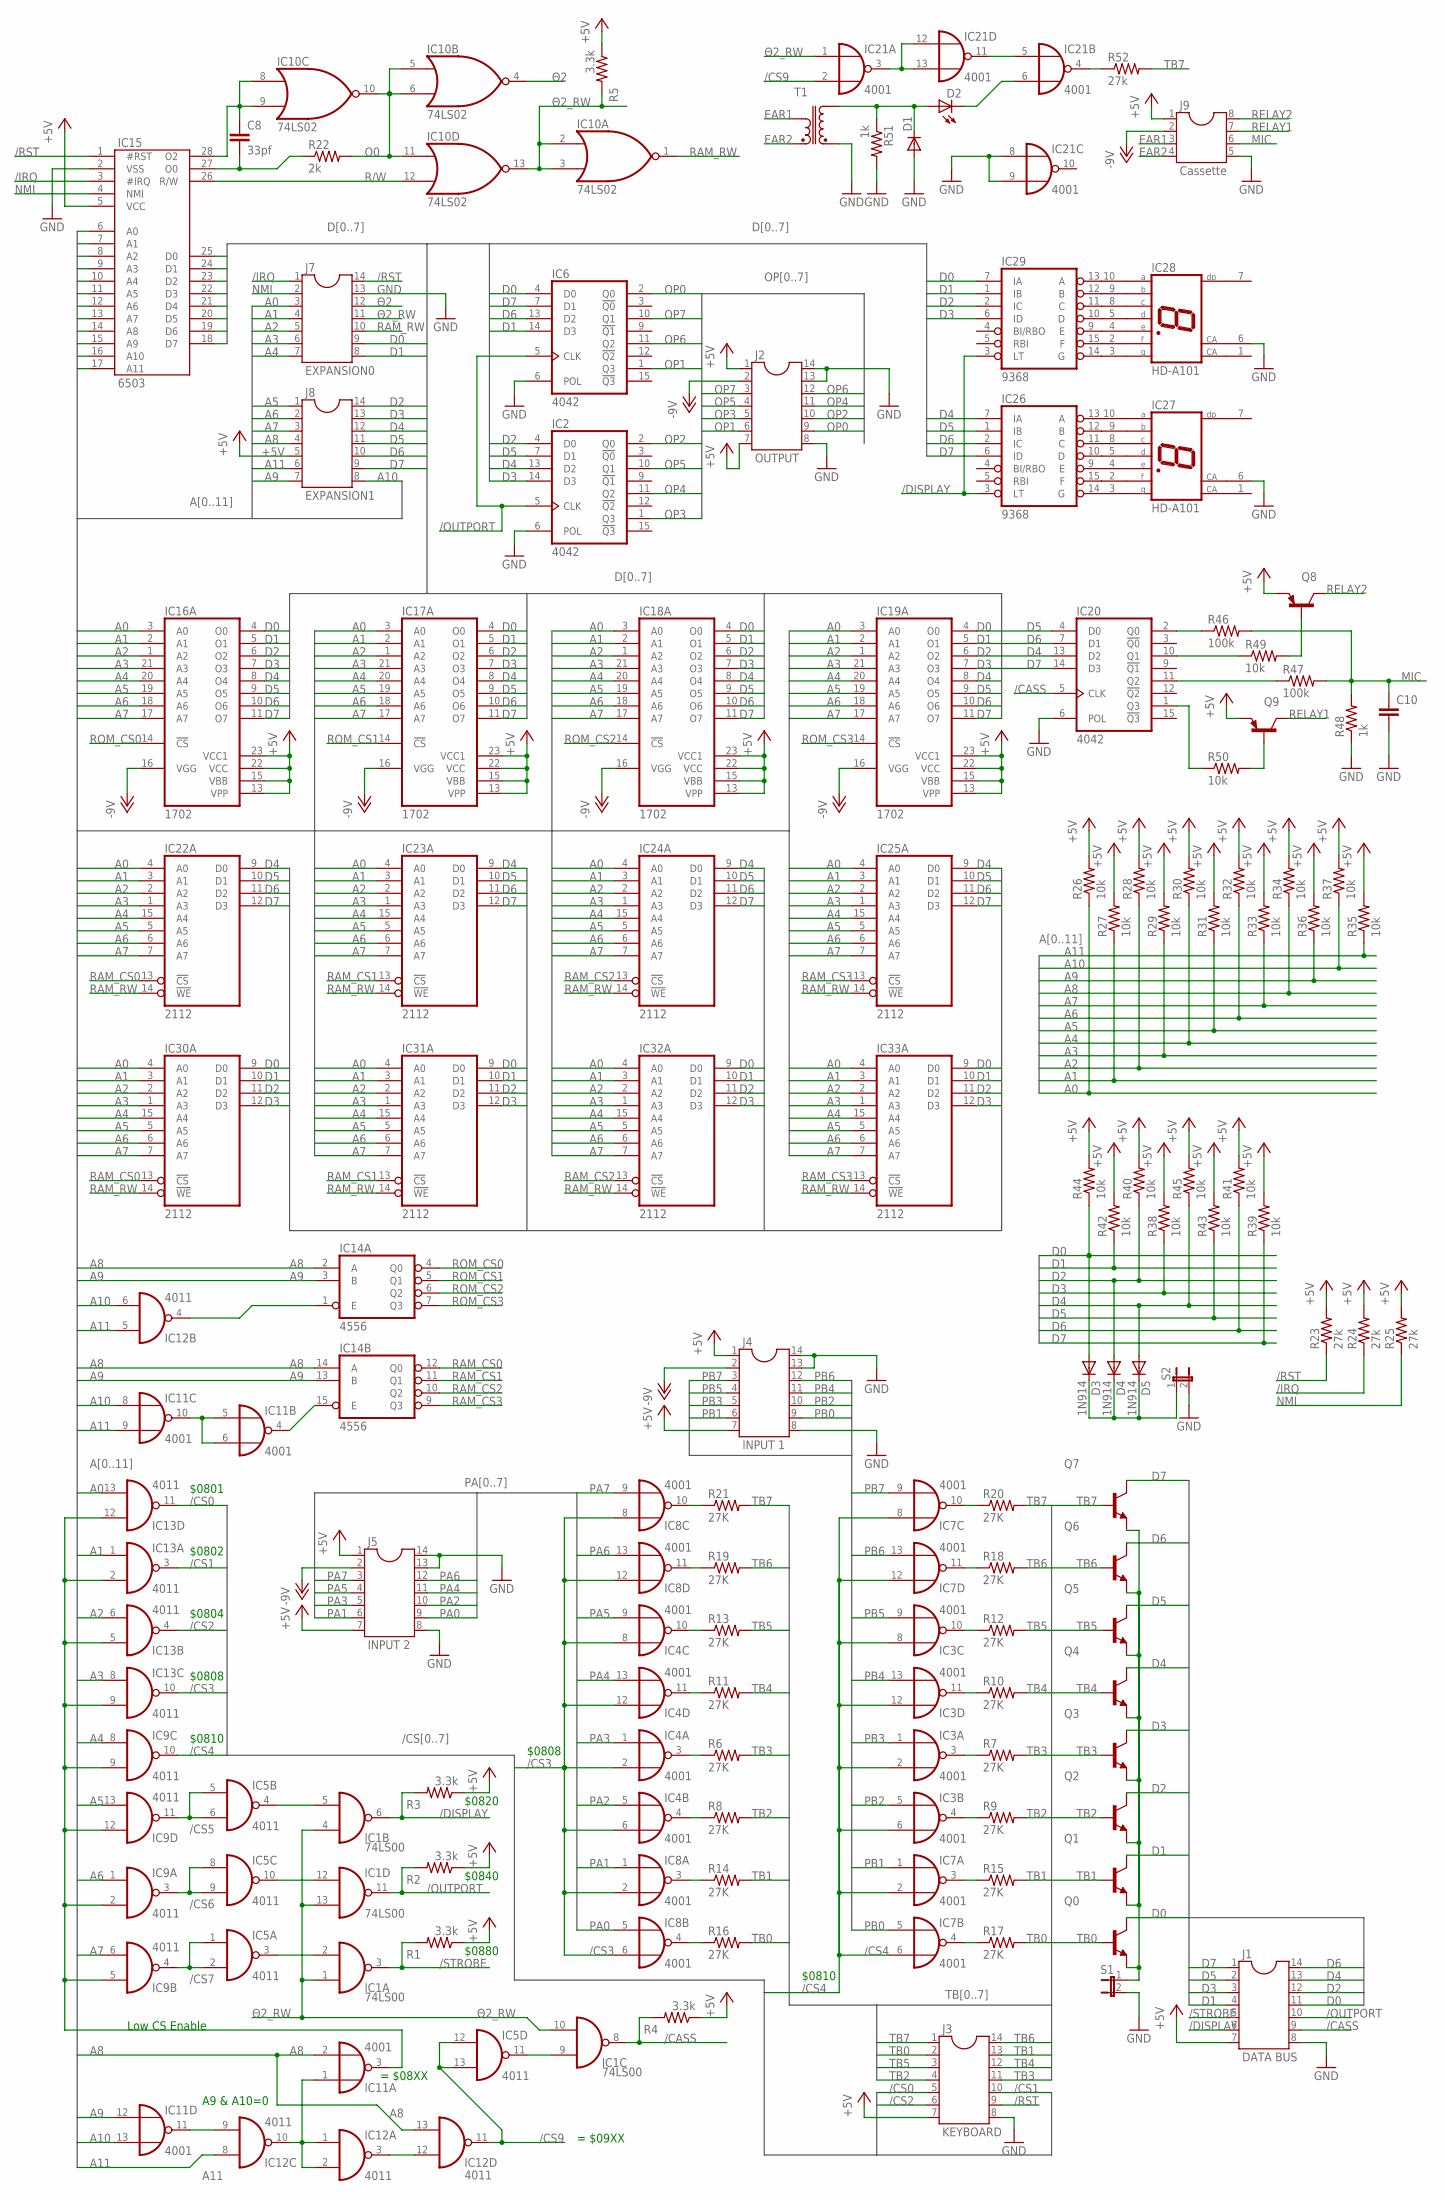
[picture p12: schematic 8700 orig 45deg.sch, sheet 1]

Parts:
C8: 33pf; C050-025X075
C10: C-EU050-025X075; C050-025X075
D1: DIODE-DO07; DO07
D2: LED3MM
D3, D4, D5: 1N914; DO07
IC1: 74LS00; DIL14
IC2, IC6, IC20: 4042; DIL16
IC3, IC4, IC7, IC8, IC11, IC21: 4001; DIL14
IC5, IC9, IC12, IC13: 4011; DIL14
IC10: 74LS02; DIL14
IC14: 4556; DIL16
IC15: 6503; DIL28-6
IC16, IC17, IC18, IC19: 1702; DIL24
IC22, IC23, IC24, IC25, IC30, IC31, IC32, IC33: 2112; DIL16
IC26, IC29: 9368; DIL16
IC27, IC28: HD-A101; HDSP-A
J1: DATA BUS; DIL14
J2: OUTPUT; DIL14
J3: KEYBOARD; DIL14
J4: INPUT 1; DIL14
J5: INPUT 2; DIL14
J7: EXPANSION0; DIL14
J8: EXPANSION1; DIL14
J9: Cassette; DIL08
Q0, Q1, Q2, Q3, Q4, Q5, Q6, Q7: 2N3904-NPN-TO92-EBC; TO92-EBC
Q8, Q9: 2N3906-PNP-TO92-EBC; TO92-EBC
R1, R2, R3, R4, R5: 3.3k; 0207/10
R6, R7, R8, R9, R10, R11, R12, R13, R14, R15, R16, R17, R18, R19, R20, R21: 27K; 0207/10
R22: 2k; 0207/10
R23, R24, R25, R52: 27k; 0207/10
R26, R27, R28, R29, R30, R31, R32, R33, R34, R35, R36, R37, R38, R39, R40, R41, R42, R43, R44, R45, R49, R50: 10k; 0207/10
R46, R47: 100k; 0207/10
R48, R51: 1k; 0207/10
S1, S2: JUMPER
T1: TRANSF

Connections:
+5V: IC15.5 (VCC), IC16.13 (VPP), IC16.15 (VBB), IC16.22 (VCC), IC16.23 (VCC1), IC17.13 (VPP), IC17.15 (VBB), IC17.22 (VCC), IC17.23 (VCC1), IC18.13 (VPP), IC18.15 (VBB), IC18.22 (VCC), IC18.23 (VCC1), IC19.13 (VPP), IC19.15 (VBB), IC19.22 (VCC), IC19.23 (VCC1), J1.7, J2.1, J2.7, J3.7, J4.1, J4.7, J5.1, J5.7, J8.5, J9.1, Q8.E, Q9.E, R1.1, R2.1, R3.1, R4.1, R5.1, R23.2, R24.2, R25.2, R26.2, R27.2, R28.2, R29.2, R30.2, R31.2, R32.2, R33.2, R34.2, R35.2, R36.2, R37.2, R38.2, R39.2, R40.2, R41.2, R42.2, R43.2, R44.2, R45.2; also elsewhere on the board
-9V: IC16.16 (VGG), IC17.16 (VGG), IC18.16 (VGG), IC19.16 (VGG), J2.2, J4.2, J5.2, J9.2; also elsewhere on the board
/CASS: IC1.8 (O), IC20.5 (CLK), J1.9, R4.2
/CS0: IC13.11 (O), J3.5
/CS1: IC13.3 (O), J3.10
/CS2: IC13.4 (O), J3.6
/CS3: IC4.2 (I1), IC4.6 (I1), IC4.8 (I0), IC4.12 (I0), IC8.2 (I1), IC8.6 (I1), IC8.8 (I0), IC8.12 (I0), IC13.10 (O)
/CS4: IC3.2 (I1), IC3.6 (I1), IC3.8 (I0), IC3.12 (I0), IC7.2 (I1), IC7.6 (I1), IC7.8 (I0), IC7.12 (I0), IC9.10 (O)
/CS5: IC5.5 (I0), IC5.6 (I1), IC9.11 (O)
/CS6: IC5.8 (I0), IC5.9 (I1), IC9.3 (O)
/CS7: IC5.1 (I0), IC5.2 (I1), IC9.4 (O)
/CS9: IC5.12 (I0), IC5.13 (I1), IC12.11 (O), IC21.2 (I1)
/DISPLAY: IC1.6 (O), IC26.3 (LT), IC29.3 (LT), J1.6, R3.2
/IRQ: IC15.3 (#IRQ), J7.1, R24.1
/OUTPORT: IC1.11 (O), IC2.5 (CLK), IC6.5 (CLK), J1.10, R2.2
/RST: IC15.1 (#RST), J3.9, J7.14, R23.1
/STROBE: IC1.3 (O), J1.5, R1.2
A0: IC13.13 (I1), IC15.6 (A0), IC16.3 (A0), IC17.3 (A0), IC18.3 (A0), IC19.3 (A0), IC22.4 (A0), IC23.4 (A0), IC24.4 (A0), IC25.4 (A0), IC30.4 (A0), IC31.4 (A0), IC32.4 (A0), IC33.4 (A0), J7.3, R26.1
A1: IC13.1 (I0), IC15.7 (A1), IC16.2 (A1), IC17.2 (A1), IC18.2 (A1), IC19.2 (A1), IC22.3 (A1), IC23.3 (A1), IC24.3 (A1), IC25.3 (A1), IC30.3 (A1), IC31.3 (A1), IC32.3 (A1), IC33.3 (A1), J7.4, R27.1
A2: IC13.6 (I1), IC15.8 (A2), IC16.1 (A2), IC17.1 (A2), IC18.1 (A2), IC19.1 (A2), IC22.2 (A2), IC23.2 (A2), IC24.2 (A2), IC25.2 (A2), IC30.2 (A2), IC31.2 (A2), IC32.2 (A2), IC33.2 (A2), J7.5, R28.1
A3: IC13.8 (I0), IC15.9 (A3), IC16.21 (A3), IC17.21 (A3), IC18.21 (A3), IC19.21 (A3), IC22.1 (A3), IC23.1 (A3), IC24.1 (A3), IC25.1 (A3), IC30.1 (A3), IC31.1 (A3), IC32.1 (A3), IC33.1 (A3), J7.6, R29.1
A4: IC9.8 (I0), IC15.10 (A4), IC16.20 (A4), IC17.20 (A4), IC18.20 (A4), IC19.20 (A4), IC22.15 (A4), IC23.15 (A4), IC24.15 (A4), IC25.15 (A4), IC30.15 (A4), IC31.15 (A4), IC32.15 (A4), IC33.15 (A4), J7.7, R30.1
A5: IC9.13 (I1), IC15.11 (A5), IC16.19 (A5), IC17.19 (A5), IC18.19 (A5), IC19.19 (A5), IC22.5 (A5), IC23.5 (A5), IC24.5 (A5), IC25.5 (A5), IC30.5 (A5), IC31.5 (A5), IC32.5 (A5), IC33.5 (A5), J8.1, R31.1
A6: IC9.1 (I0), IC15.12 (A6), IC16.18 (A6), IC17.18 (A6), IC18.18 (A6), IC19.18 (A6), IC22.6 (A6), IC23.6 (A6), IC24.6 (A6), IC25.6 (A6), IC30.6 (A6), IC31.6 (A6), IC32.6 (A6), IC33.6 (A6), J8.2, R32.1
A7: IC9.6 (I1), IC15.13 (A7), IC16.17 (A7), IC17.17 (A7), IC18.17 (A7), IC19.17 (A7), IC22.7 (A7), IC23.7 (A7), IC24.7 (A7), IC25.7 (A7), IC30.7 (A7), IC31.7 (A7), IC32.7 (A7), IC33.7 (A7), J8.3, R33.1
A8: IC11.2 (I1), IC12.13 (I1), IC14.2 (A), IC14.14 (A), IC15.14 (A8), J8.4, R34.1
A9: IC11.12 (I0), IC14.3 (B), IC14.13 (B), IC15.15 (A9), J8.7, R36.1
A10: IC11.8 (I0), IC11.13 (I1), IC12.6 (I1), IC15.16 (A10), J8.8, R37.1
A11: IC11.9 (I1), IC12.5 (I0), IC12.8 (I0), IC15.17 (A11), J8.6, R35.1
D0: D3.A, IC6.4 (D0), IC15.25 (D0), IC16.4 (O0), IC17.4 (O0), IC18.4 (O0), IC19.4 (O0), IC29.7 (IA), IC30.9 (D0), IC31.9 (D0), IC32.9 (D0), IC33.9 (D0), J1.11, J7.9, Q0.C, R44.1
D1: IC6.14 (D3), IC15.24 (D1), IC16.5 (O1), IC17.5 (O1), IC18.5 (O1), IC19.5 (O1), IC29.1 (IB), IC30.10 (D1), IC31.10 (D1), IC32.10 (D1), IC33.10 (D1), J1.4, J7.8, Q1.C, R42.1
D2: D4.A, IC2.4 (D0), IC15.23 (D2), IC16.6 (O2), IC17.6 (O2), IC18.6 (O2), IC19.6 (O2), IC29.2 (IC), IC30.11 (D2), IC31.11 (D2), IC32.11 (D2), IC33.11 (D2), J1.12, J8.14, Q2.C, R40.1
D3: IC2.14 (D3), IC15.22 (D3), IC16.7 (O3), IC17.7 (O3), IC18.7 (O3), IC19.7 (O3), IC29.6 (ID), IC30.12 (D3), IC31.12 (D3), IC32.12 (D3), IC33.12 (D3), J1.3, J8.13, Q3.C, R38.1
D4: D5.A, IC2.13 (D2), IC15.21 (D4), IC16.8 (O4), IC17.8 (O4), IC18.8 (O4), IC19.8 (O4), IC20.13 (D2), IC22.9 (D0), IC23.9 (D0), IC24.9 (D0), IC25.9 (D0), IC26.7 (IA), J1.13, J8.12, Q4.C, R45.1
D5: IC2.7 (D1), IC15.20 (D5), IC16.9 (O5), IC17.9 (O5), IC18.9 (O5), IC19.9 (O5), IC20.4 (D0), IC22.10 (D1), IC23.10 (D1), IC24.10 (D1), IC25.10 (D1), IC26.1 (IB), J1.2, J8.11, Q5.C, R43.1
D6: IC6.13 (D2), IC15.19 (D6), IC16.10 (O6), IC17.10 (O6), IC18.10 (O6), IC19.10 (O6), IC20.7 (D1), IC22.11 (D2), IC23.11 (D2), IC24.11 (D2), IC25.11 (D2), IC26.2 (IC), J1.14, J8.10, Q6.C, R41.1
D7: IC6.7 (D1), IC15.18 (D7), IC16.11 (O7), IC17.11 (O7), IC18.11 (O7), IC19.11 (O7), IC20.14 (D3), IC22.12 (D3), IC23.12 (D3), IC24.12 (D3), IC25.12 (D3), IC26.6 (ID), J1.1, J8.9, Q7.C, R39.1
EAR1: J9.3, T1.P$1 (P1)
EAR2: J9.4, T1.P$2 (P2)
GND: C10.2, D1.A, IC2.6 (POL), IC6.6 (POL), IC15.2 (VSS), IC20.6 (POL), IC21.8 (I0), IC21.9 (I1), IC27.6 (CA), IC28.6 (CA), J1.8, J2.8, J2.13, J2.14, J3.8, J4.8, J4.13, J4.14, J5.8, J5.13, J5.14, J7.13, J9.5, R48.1, R51.2, S1.2, S2.2, T1.P$5 (S1); also elsewhere on the board
MIC: C10.1, J9.6, R46.2, R47.2, R48.2
unnamed: C8.1, IC10.8 (I0), IC10.9 (I1), IC15.28 (O2)
unnamed: IC21.3 (O), IC21.12 (I0), IC21.13 (I1)
unnamed: C8.2, IC15.27 (O0), R22.1
unnamed: D2.K (C), IC21.6 (I1)
unnamed: IC21.5 (I0), IC21.11 (O)
unnamed: IC21.4 (O), R52.1
unnamed: Q0.E, Q1.E, Q2.E, Q3.E, Q4.E, Q5.E, Q6.E, Q7.E, S1.1
unnamed: IC9.2 (I1), IC9.5 (I0), IC9.9 (I1), IC9.12 (I0), IC11.3 (O), IC13.2 (I1), IC13.5 (I0), IC13.9 (I1), IC13.12 (I0)
unnamed: IC1.2 (I1), IC5.3 (O)
unnamed: IC1.5 (I1), IC5.4 (O)
unnamed: IC12.4 (O), IC14.1 (E)
unnamed: IC11.5 (I0), IC11.6 (I1), IC11.10 (O)
unnamed: IC1.12 (I0), IC5.10 (O)
unnamed: IC11.4 (O), IC14.15 (E)
unnamed: IC11.11 (O), IC12.9 (I1)
unnamed: IC11.1 (I0), IC12.1 (I0), IC12.2 (I1), IC12.10 (O)
unnamed: IC12.3 (O), IC12.12 (I0)
unnamed: IC1.9 (I0), IC5.11 (O)
unnamed: IC8.3 (O), R14.1
unnamed: IC8.4 (O), R16.1
unnamed: IC20.11 (Q2), R47.1
unnamed: IC4.4 (O), R8.1
unnamed: IC4.3 (O), R6.1
unnamed: IC4.11 (O), R11.1
unnamed: IC4.10 (O), R13.1
unnamed: IC8.11 (O), R19.1
unnamed: IC8.10 (O), R21.1
unnamed: IC7.4 (O), R17.1
unnamed: IC7.3 (O), R15.1
unnamed: IC3.4 (O), R9.1
unnamed: IC3.3 (O), R7.1
unnamed: IC3.11 (O), R10.1
unnamed: IC3.10 (O), R12.1
unnamed: IC7.11 (O), R18.1
unnamed: IC7.10 (O), R20.1
unnamed: IC20.1 (Q3), R50.1
unnamed: IC28.2 (F), IC29.15 (F)
unnamed: IC28.5 (D), IC29.10 (D)
unnamed: Q9.B, R50.2
unnamed: Q8.B, R49.2
unnamed: IC28.9 (B), IC29.12 (B)
unnamed: IC28.10 (A), IC29.13 (A)
unnamed: IC20.2 (Q0), R46.1
unnamed: IC20.10 (Q1), R49.1
unnamed: IC28.8 (C), IC29.11 (C)
unnamed: IC28.4 (E), IC29.9 (E)
unnamed: IC28.3 (G), IC29.14 (G)
unnamed: IC26.15 (F), IC27.2 (F)
unnamed: IC26.10 (D), IC27.5 (D)
unnamed: IC26.12 (B), IC27.9 (B)
unnamed: IC26.13 (A), IC27.10 (A)
unnamed: IC26.11 (C), IC27.8 (C)
unnamed: IC26.9 (E), IC27.4 (E)
unnamed: IC26.14 (G), IC27.3 (G)
unnamed: D3.C, D4.C, D5.C, S2.1
unnamed: D1.C, D2.A, R51.1, T1.P$3 (S2)
NMI: IC15.4 (NMI), J7.2, R25.1
O0: IC10.5 (I0), IC10.6 (I1), IC10.10 (O), IC10.11 (I0), R22.2
OP0: IC6.2 (Q0), J2.9
OP1: IC6.1 (Q3), J2.6
OP2: IC2.2 (Q0), J2.10
OP3: IC2.1 (Q3), J2.5
OP4: IC2.11 (Q2), J2.11
OP5: IC2.10 (Q1), J2.4
OP6: IC6.11 (Q2), J2.12
OP7: IC6.10 (Q1), J2.3
PA0: IC8.5 (I0), J5.9
PA1: IC8.1 (I0), J5.6
PA2: IC4.5 (I0), J5.10
PA3: IC4.1 (I0), J5.5
PA4: IC4.13 (I1), J5.11
PA5: IC4.9 (I1), J5.4
PA6: IC8.13 (I1), J5.12
PA7: IC8.9 (I1), J5.3
PB0: IC7.5 (I0), J4.9
PB1: IC7.1 (I0), J4.6
PB2: IC3.5 (I0), J4.10
PB3: IC3.1 (I0), J4.5
PB4: IC3.13 (I1), J4.11
PB5: IC3.9 (I1), J4.4
PB6: IC7.13 (I1), J4.12
PB7: IC7.9 (I1), J4.3
R/W: IC10.12 (I1), IC15.26 (R/W)
RAM_CS0: IC14.12 (Q0), IC22.13 (!CS), IC30.13 (!CS)
RAM_CS1: IC14.11 (Q1), IC23.13 (!CS), IC31.13 (!CS)
RAM_CS2: IC14.10 (Q2), IC24.13 (!CS), IC32.13 (!CS)
RAM_CS3: IC14.9 (Q3), IC25.13 (!CS), IC33.13 (!CS)
RAM_RW: IC10.1 (O), IC22.14 (!WE), IC23.14 (!WE), IC24.14 (!WE), IC25.14 (!WE), IC30.14 (!WE), IC31.14 (!WE), IC32.14 (!WE), IC33.14 (!WE), J7.10
RELAY1: J9.7, Q9.C
RELAY2: J9.8, Q8.C
ROM_CS0: IC14.4 (Q0), IC16.14 (!CS)
ROM_CS1: IC14.5 (Q1), IC17.14 (!CS)
ROM_CS2: IC14.6 (Q2), IC18.14 (!CS)
ROM_CS3: IC14.7 (Q3), IC19.14 (!CS)
TB0: J3.2, Q0.B, R16.2, R17.2
TB1: J3.13, Q1.B, R14.2, R15.2
TB2: J3.4, Q2.B, R8.2, R9.2
TB3: J3.11, Q3.B, R6.2, R7.2
TB4: J3.12, Q4.B, R10.2, R11.2
TB5: J3.3, Q5.B, R12.2, R13.2
TB6: J3.14, Q6.B, R18.2, R19.2
TB7: J3.1, Q7.B, R20.2, R21.2, R52.2
Θ2: IC10.4 (O), J7.12
Θ2_RW: IC1.1 (I0), IC1.4 (I0), IC1.10 (I1), IC1.13 (I1), IC10.2 (I0), IC10.3 (I1), IC10.13 (O), IC21.1 (I0), J7.11, R5.2

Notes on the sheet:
Low CS Enable
A9 & A10=0
= $09XX
= $08XX
$0820
$0840
$0880
$0810
$0808
$0804
$0802
$0801

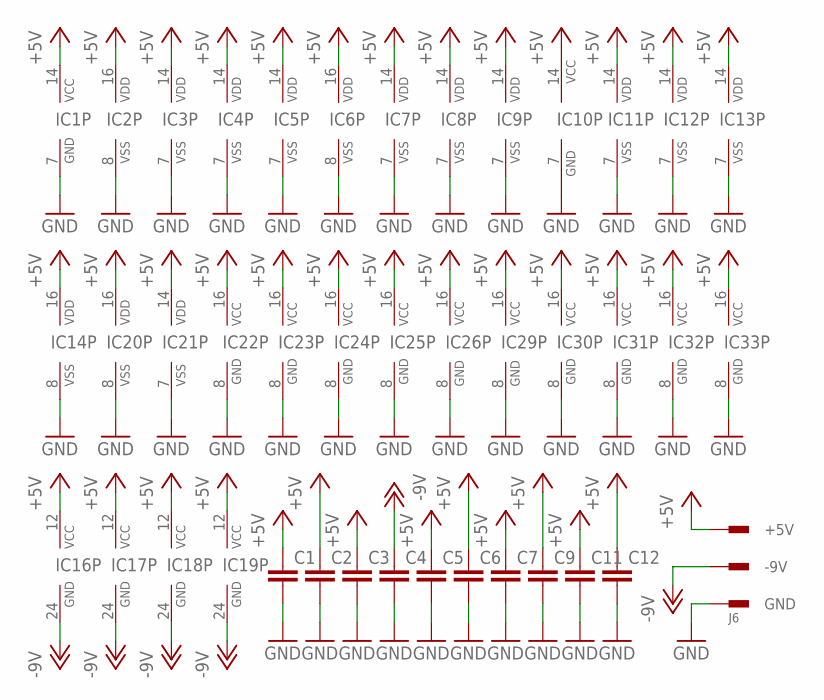
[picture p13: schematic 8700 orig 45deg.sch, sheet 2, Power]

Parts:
C1, C2, C3, C4, C5, C6, C7, C9, C11, C12: C-EU050-025X075; C050-025X075
IC1: 74LS00; DIL14
IC2, IC6, IC20: 4042; DIL16
IC3, IC4, IC7, IC8, IC11, IC21: 4001; DIL14
IC5, IC9, IC12, IC13: 4011; DIL14
IC10: 74LS02; DIL14
IC14: 4556; DIL16
IC16, IC17, IC18, IC19: 1702; DIL24
IC22, IC23, IC24, IC25, IC30, IC31, IC32, IC33: 2112; DIL16
IC26, IC29: 9368; DIL16
J6: POWER

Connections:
+5V: C1.1, C2.1, C3.1, C5.1, C6.1, C7.1, C9.1, C11.1, C12.1, IC1.14 (VCC), IC2.16 (VDD), IC3.14 (VDD), IC4.14 (VDD), IC5.14 (VDD), IC6.16 (VDD), IC7.14 (VDD), IC8.14 (VDD), IC9.14 (VDD), IC10.14 (VCC), IC11.14 (VDD), IC12.14 (VDD), IC13.14 (VDD), IC14.16 (VDD), IC16.12 (VCC), IC17.12 (VCC), IC18.12 (VCC), IC19.12 (VCC), IC20.16 (VDD), IC21.14 (VDD), IC22.16 (VCC), IC23.16 (VCC), IC24.16 (VCC), IC25.16 (VCC), IC26.16 (VCC), IC29.16 (VCC), IC30.16 (VCC), IC31.16 (VCC), IC32.16 (VCC), IC33.16 (VCC), J6.P$1 (+5V); also elsewhere on the board
-9V: C4.1, IC16.24 (GND), IC17.24 (GND), IC18.24 (GND), IC19.24 (GND), J6.P$2 (-9V); also elsewhere on the board
GND: C1.2, C2.2, C3.2, C4.2, C5.2, C6.2, C7.2, C9.2, C11.2, C12.2, IC1.7 (GND), IC2.8 (VSS), IC3.7 (VSS), IC4.7 (VSS), IC5.7 (VSS), IC6.8 (VSS), IC7.7 (VSS), IC8.7 (VSS), IC9.7 (VSS), IC10.7 (GND), IC11.7 (VSS), IC12.7 (VSS), IC13.7 (VSS), IC14.8 (VSS), IC20.8 (VSS), IC21.7 (VSS), IC22.8 (GND), IC23.8 (GND), IC24.8 (GND), IC25.8 (GND), IC26.8 (GND), IC29.8 (GND), IC30.8 (GND), IC31.8 (GND), IC32.8 (GND), IC33.8 (GND), J6.P$3 (GND); also elsewhere on the board

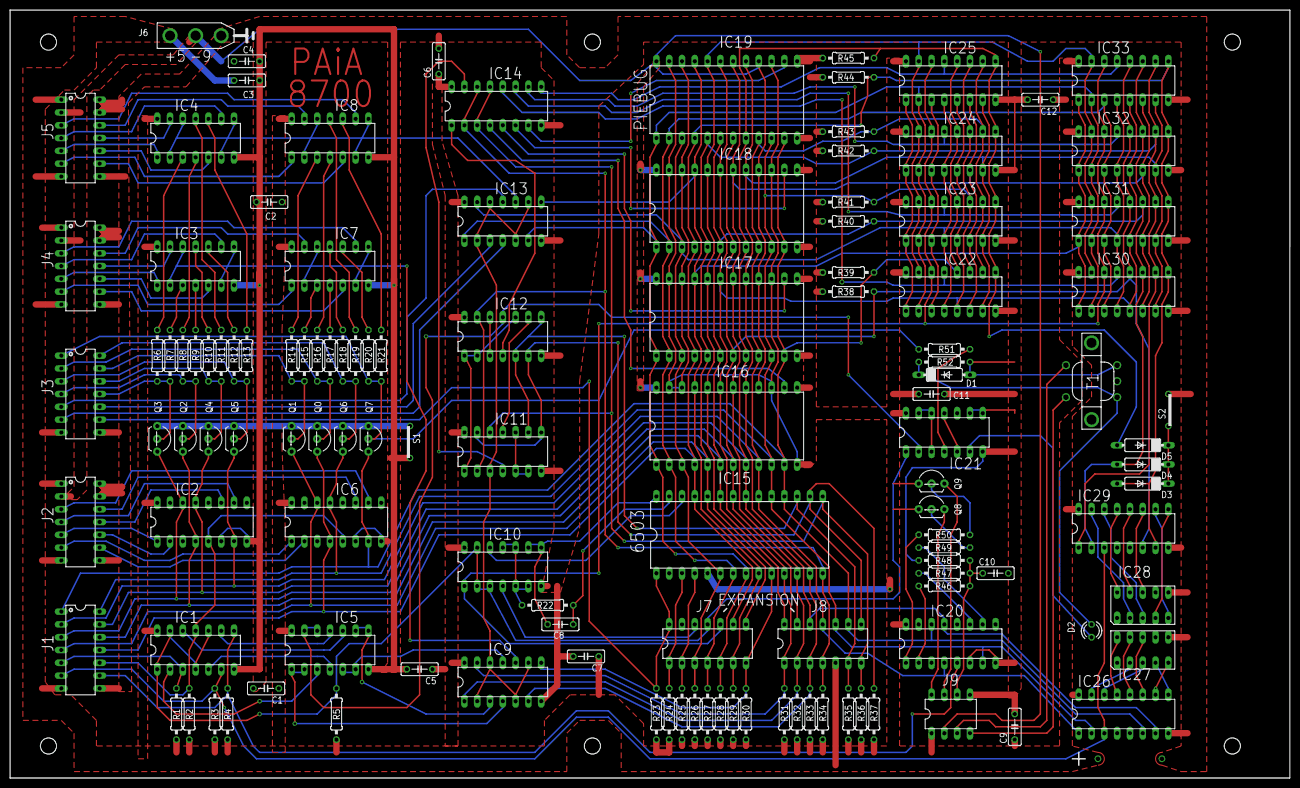
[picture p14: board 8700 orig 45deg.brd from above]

Board: 2 copper layers, 254.0 x 152.4 mm, 124 parts (0 on the bottom side), 145 nets.

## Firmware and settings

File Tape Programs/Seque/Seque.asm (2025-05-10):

;********************************
;*                              *
;*          SEQUE 1.0           *
;*                              *
;* MONOTONIC SEQUENCER PROGRAMS *
;*                              *
;*             BY               *
;*    JOHN S. SIMONTON, JR.     *
;*                              *
;*(C) 1978 PAIA ELECTRONICS, INC*
;*     ALL RGIHTS RESERVED      *
;*                              *
;********************************
;
;DEFINE ADDRESS OF LABELS
;
BEEP	=$1F22
DECD	=$1F00	
CASS	=$1EAA
DBIT	=$1E49
SBIT	=$1E25
OUTP	=$0840 ;$09FF IN TAPE DUMP
DSP		=$0820
KBD		=$0810
;
MTBL3	=$0303
MTBL2	=$0302
MTBL1	=$0301
MTBL	=$0300
TTBL	=$02C0
;
BUFF	=$00F0
KBUF	=$00EC
PBUF	=$00EB
MPNT	=$00EA
TPNT	=$00E9
MEND	=$00E8
TEND	=$00E7
TRNS	=$00E6
CNTR	=$00E5
TTRN	=$00E4
LSTL	=$00E3
STUS	=$00E2
TPO		=$00E1
METF	=$00E0
MTRC	=$00DF
DUMY	=$0003
;
;
;
		org	$1000
;
STAR	lda	#$00	;START / RESTART
		sta	STUS	;CANCEL OPTIONS
		lda	#$0C	;NRML COMMAND LINK
		sta	ACTN+01	;PLACE COMMAND LINK
		jmp	COM		;JUMP TO COMMON
;
;NORMAL OPERATING MODE - DOES NOT ALTER
;T-SEQUENCE OR M-SEQUENCE
;
NRML	bcs	NRM1	;FIRST PASS THROUGH
		sta	TRNS	;ZERO TRANSPOSE
		sta	DSP		;AND DISPLAYS
NRM1	lda	KBUF	;CHECK FOR NOTES
		bne	STOR	;ZERO- NO NEW KEY
 		lda	PBUF	;SO GET OLD KEY
 		and	#$3F	;CLEAR BOTH FLAGS
STOR	sta	PBUF	;SAVE AGAIN
 		rts			;AND RETURN
;
;PROGRAM TRANSPOE MODE - NOTE PLAYED
;IS "KILLED" WHEN KEY IS RELEASED
;
TLOD	bcs	TL1		;FIRST PASS, INITIALIZE
		sta	TRNS	;ZERO TRANSPOSE FIGURE
 		sta	PBUF	;ZERO OUTPUT NOTE
 		sta	TEND	;ZERO TABLE END POINTER
		lda	#$80	;TURN T-SEQUE OPTION
 		sta	STUS	;ON
TL1		ldx	TEND	;GET TRANSPOSE POINTER
		stx	DSP		;SHOW IT
		lda	KBUF	;GET THE NOTE
		beq	TL2		;ZERO- NO KEY, SAVE
		cmp	PBUF	;KEY SAME AS LAST?
		beq	TRTN	;YES - LEAVE
		inc	TEND	;POINT TO NEXT LOCATION
TL2		sta	TTBL,x	;SAVE TRANSPOSE
TRTN	sta	PBUF	;AND OUTPUT AS NOTE
		rts			;THEN RETURN
;
;PROGRAM SCORE MODE - USES REAL-TIME CLOCK
;
MSAV	jsr	MSV1	;CALL SAVE MODULE
 		inc	CNTR	;INCREMENT THE TEMPO
 		rts			;COUNTER AND RETURN
;
;CONTINUE PLAY MODE - DOES NOT RESET
;M-SEQUENCE OR T-SEQUENCE POINTERS
;
CNTU	sec			;SKIP INITIALIZATION
;
;REPEAT PLAY MODE - WHEN FIRST ENTERED
;M-SEQ AND T-SEQ POINTERS ARE SET TO ZERO
;BY THE PLAY MODULE (PLA1)
;
RPLA	jsr	PLA1	;CALL PLAY MODULE
		lda	STBL+$14;WAS THE PREVIOUS MODE
 		cmp	LSTL	;MSAV (PROG. SCORE)?
 		bne	RPL1	;NO-SKIP INCREMENT
 		inc	TPNT	;INC. T-SEQ POINTER
RPL1	bit	STUS	;T-SEQ ASSERTED ?
 		bmi	ROUT	;OPTION ON - LEAVE
 		lda	KBUF	;OPTION OFF- GET NOTE
 		beq	OLDK	;AND IF NO NOTE, BRANCH
 		sta	TTRN	;SAVE NOTE FOR NEXT TIME
OLDK	lda	TTRN	;GET LAST ACTIVE NOTE
 		sta	TRNS	;USE AS TRANSPOSE
ROUT	inc	CNTR	;INCREMENT TEMPO COUNTER
 		rts			;AND RETURN
;
;SINGLE PLAY MODE - WAITS FOR AGO KEY
;THEN PLAYS SEQUENCE ONCE THROUGH
;TRANSPOSED TO INDICAtED KEY
;
SING	bcc	SNG1	;FIRST PASS, BRANCH
 		lda	KBUF	;AGO KEY DOWN?
 		bne	RPLA	;YES - PLAY SEQUENCE
SNG1	jsr	RPLA	;NO - "PLAY" THEN RETURN
 		lda	MPNT	;M-SEQ POINTER > 0 ?
 		bne	SRTN	;YES - RETURN
		lda	#$00	;NO - PREPARE
 		sta	CNTR	;ZERO TEMPO COUNTER
 		ldx	MEND	;POINT TO LAST NOTE
		lda	MTBL1,x	;OF M-SEQ AND GET IT
 		sta	PBUF	;PLACE IN PLAY BUFFER
SRTN	rts			;THEN RETURN
;
;UP TEMPO AND DOWN TEMPO - COMMON PORTION
;OF BOTH PROGRAMS ON PAGE 2
;
UTMP	lda	#$7E	;THE OP-CODE FOR ROR
		bne	U_D		;BRANCH ALWAYS
DTMP	lda	#$3E	;THE OP-CODE FOR ROL
U_D		jmp	TCOM	;JUMP FOR THE REST
;
;REST MODE - EXTENDS NOTES OR UN-NOTES
;WHEN IN PROGRAM EVENT MODE
;
REST	clc			;PREPARE FOR ADDITTION
 		lda	CNTR	;GET TEMPO COUNTER
 		adc	TPO		;ADD TEMPO VALUE
 		sta	CNTR	;PUT COUNTER BACK
 		lda	LSTL	;AND RETURN TO
		sta	ACTN+01	;PREVIOUS OPERATING
 		rts			;MODE
;
;STOP/STEP MODE - STOPS PLAY WITHOUT
;CHANGING POINTERS. SINGLE STEPS THROUGH
;SEQUENCE
;
STEP	bcs	STP1	;NOT FIRST PASS=BRANCH
		lda	#$FF	;SET TEMPO COUNTER AT
		sta	CNTR	;"TIMED OUT" VALUE
		jsr	CONT	;CALL PART OF PLAY MODULE
		stx	DSP		;DISPLAY M-SEQ POINTER
		lda	#$00	;MAKE TRANSPOSE VALUE
		sta	TRNS	;EQUAL TO ZERO
STP1	rts			;AND RETURN
;
;PROGRAM EVENT MODE - SAVES M-SEQUENCE
;BUT SUBSTITUTES EVENT CLOCK FOR REAL-TIME
;CLOCK
;
ESAV	bcs	ES1		;FIRST PASS, INITIALIZE
		sta	CNTR	;TEMPO COUNTER AS ZERO
ES1		jsr	MSV1	;CALL SAVE MODULE
		lda	CNTR	;GET TEMPO COUNTER
		bne	EOUT	;NO ENTRY-RETURN
		clc			;PREPARE
		adc	TPO		;ADD TEMPO VALUE
		sta	CNTR	;SAVE AS TEMPO COUNTER
EOUT	rts			;TEHN RETURN
;
;OPTION MENU - RETURN TO PREVIOUS
;OPERATING MODE AFTER TURING ON OR
;CANCELLING OPTIONS
;
TBLM	sta	TPNT	;T-SEQ POINTER TO BEG
		lda	STUS	;ASSERT T-SEQ OPTION
		ora	#$80
		bne	MCOM	;BRANCH ASLWAYS
MET		lda	STUS	;TURN METRONOME ON
		ora	#$40
		bne	MCOM	;BRANCH ALWAYS
SYNC	lda	STUS	;TURN ON SYNC TO
		ora	#$01	;CLICK TRACK OPTION
		bne	MCOM	;BRANCH ALWAYS
CNCL	lda	#$00	;PREPARE AND
MCOM	sta	STUS	;CANCEL ALL OPTIONS
		jmp	TCM1	;JUMP FOR THE REST
;
;CLICK MODE - SEND CLICK TRACK TO TAPE
;AGO KEYBOARD SCAN RATE IS TIME
;
CLIK	clc			;PREPARE TO SEND "0"
		jsr	SBIT	;SEND IT
 		rts			;RETURN FOR KEYBOARD DELAY
;
;METRONOME TEMPO CHANGE - PROGRAM ON PAGE 2
;
TCHG	jmp	TCH		;JUMP TO PROGRAM
;
;DUMP M&T-SEQ TO TAPE - PROGRAM ON PAGE 2
;
OTAP	jmp	TOUT	;JUMP TO PROGRAM
;
;LOAD M&T-SEQ FROM TAPE - PROGRAM ON PAGE 2
;
ITAP	jmp	TIN		;JUMP TO PROGRAM
;
;
;COMMAND LINKS - LOW BYTE OF ADDRESS OF SUBS
;
	org $1100
STBL
		db	lo REST, lo REST, lo REST, lo REST
		db	lo SYNC, lo MET,  lo TBLM, lo CNCL
		db	lo CLIK, lo TCHG, lo DTMP, lo UTMP
		db	lo ITAP, lo OTAP, lo NRML, lo NRML
		db	lo CNTU, lo STEP, lo SING, lo RPLA
		db	lo MSAV, lo ESAV, lo TLOD, lo RPLA
;
	org $1118
;
;COMMON PROGRAM - DOES METRONOME WHEN ON
;ADDS PLAY AND TRASNPOSE BUFFERS TO GET
;OUTPUT NOTE, PLAYS NOTE, READS COMMAND
;KEYBOARD AND JUMPS TO SELECTED MODE
;SUBSTITUES CLICK SYNCH FOR KEYBOARD
;TIMING LOOP WHEN SYNC OPTION IS ASSERTED
;
COM		lda STUS	;CHECK OPTIONS
 		pha			;SAVE A COPY
 		asl	a		;METRONOME ON ?
 		bpl	COM0	;NO - BRANCH
 		dec	MTRC	;DECREMENT METRONOME COUNTER
		bpl	COM0	;NOT <0 YET, BRANCH
		ldx	TPO		;TIME UP, GET TEMPO VALUE
		dex			;DECREMENT ONCE
		stx	MTRC	;THEN SAVE AS COUNTER
		lda	#$80	;TO DETERMINE ALTERNATE DISPLAY
		tax			;CYCLE AND "PENDULUM" LEFT
		clc			;PREPARE FOR ADDITTION
		adc	METF	;ADD FLIP-FLOP VALUE
		sta	METF	;SAVE NEW VALUE
		bpl	MET1	;ALTERNATE? - DISPLAY
		lda	PBUF	;OTHERWISE, GET OUTPUT
		ora	#$80	;SET D7
		sta	PBUF	;SAVE IN PLAY BUFFER
		clc			;PREPARE AND
		jsr	SBIT	;CALL BEEP
		ldx	#$08	;"PENDULUM" RIGHT
MET1	stx	DSP		;SHOW PENDULUM
COM0	lda	TRNS	;IS THERE A TRANSPOSE ?
		beq	COM1	;NO - BRANCH
TRAN	clc			;YES - PREPARE
		adc	#$A4	;CALCULATE TRANSPOSE VALUE
COM1	clc			;MORE PREPARATION
		adc	PBUF	;CALCULATE NOTE
COUT	sta	OUTP	;PLAY NOTE
		pla			;GET STUS (OPTION CODES)
		ror	a		;SYNC OPTION ON ?
		bcc	KRED	;NO - SKIP
		jsr	DBIT	;WAIT FOR CLIK
		jmp	CTRL	;SKIP READING AGO
;
KRED	bit	KBD		;WAIT FOR DUMMY SCAN
		bpl	KRED	;LOOP UNTIL STARTED
KR2		lda	KBD		;WAIT FOR SCAN TO START
		bmi	KR2		;LOOP UNTIL STARTED
KR3		bit	KBD		;CHECK FOR KEYS DOWN
		bmi	KRTN	;WHEN SCAN DONE, RETURN
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

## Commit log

2019-02-17 Initial upload
    [8700 orig 45deg.brd, 8700 orig 45deg.sch]
2019-02-18 Uploading memory map
    [8700 Memory Map.xls]
2020-10-18 Added tape tools/programs. Assemble with as65
2022-03-09 Added MUS-1 assembly source (commented)
2022-04-25 Adding Poly-Split comments and assembly file

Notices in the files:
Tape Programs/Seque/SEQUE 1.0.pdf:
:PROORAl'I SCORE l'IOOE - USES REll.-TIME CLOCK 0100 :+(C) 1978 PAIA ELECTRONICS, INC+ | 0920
